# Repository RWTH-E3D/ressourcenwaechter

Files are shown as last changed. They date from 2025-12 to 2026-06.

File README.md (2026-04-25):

# Ressourcenwächter

*Resource Guardian - An open-source, modular Indoor Environmental Quality (IEQ) monitoring system featuring a gamified Graphical User Interface (GUI)*

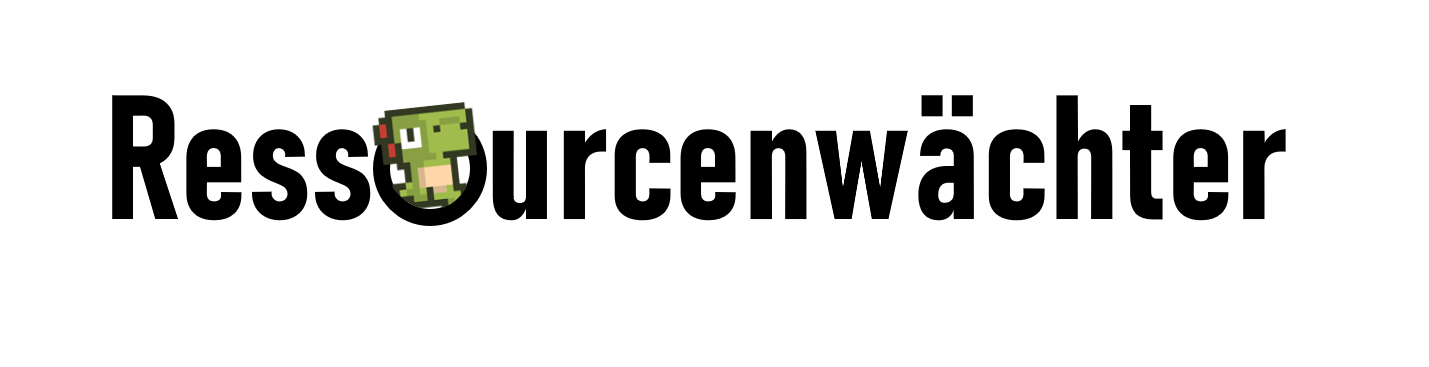
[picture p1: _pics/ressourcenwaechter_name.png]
Ressourcenwaechter name


**Resource Guardian's Wiki: [Link](https://rw.e3d.rwth-aachen.de/en/homepage-en/)**

## Overview

<!-- TOC -->
- [Ressourcenwächter](#ressourcenwächter)
  - [Overview](#overview)
  - [Key Features](#key-features)
  - [Design](#design)
  - [DIY Guide](#diy-guide)
  - [License](#license)
    - [Software \& Firmware](#software--firmware)
    - [Hardware](#hardware)
    - [Feedback System (Texts \& Concepts)](#feedback-system-texts--concepts)
    - [Documentation](#documentation)
    - [Artworks](#artworks)
  - [Acknowledgements](#acknowledgements)
  - [How to cite](#how-to-cite)
  - [Contributors](#contributors)
<!-- TOC -->

## Key Features

- **Modular IEQ monitoring system**

  Open-source system for monitoring key IEQ parameters, designed for real-world field studies and long-term deployment.

- **Multi-sensor data acquisition**

  Support for air temperature, humidity, illuminance, sound level, CO<sub>2</sub> concentration, VOC, wind speed, window status, electric power, and other IEQ sensors, with synchronized data collection and time-stamping.

- **Autonomous system**

  On-device GUI providing real-time visualization, intuitive interaction, and immediate feedback without requiring an external computer or internet connection. All data are stored locally on a microSD card.

- **Behavior-oriented feedback system**

  Context-aware feedback and recommendations aiming to support more resource-/energy-efficient and healthy user behavior, based on measured IEQ conditions.

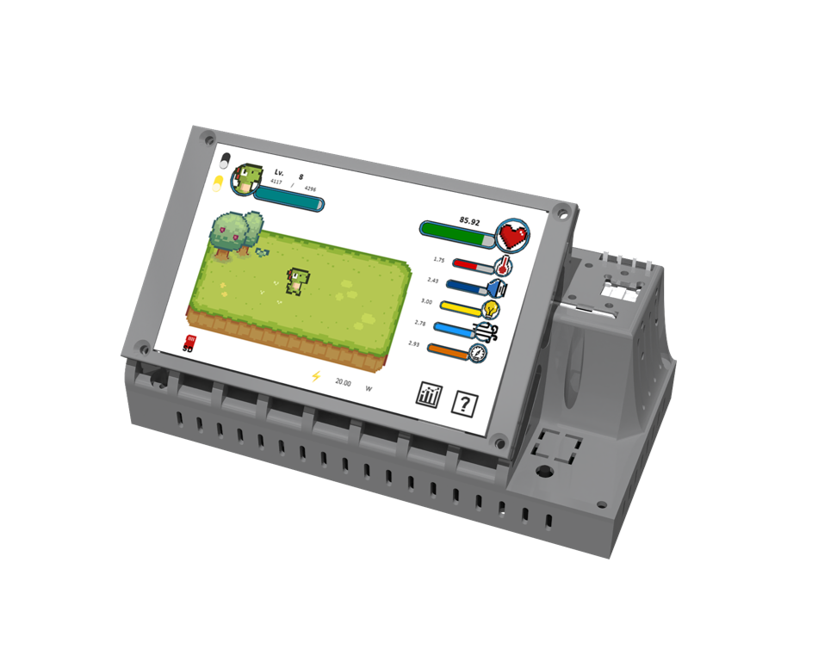
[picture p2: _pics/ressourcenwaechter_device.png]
Ressourcenwaechter monitoring device


<table>
<tr>
  <td align="center" valign="top">
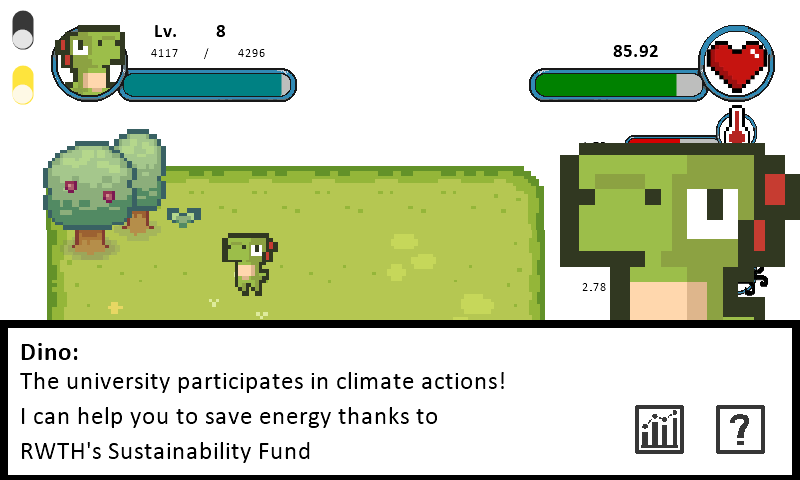
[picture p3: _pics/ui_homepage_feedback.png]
Feedback System
      
      <br/>
      <sub><strong>Feedback System</strong><br/>Resource Guardian can provide recommendations and energy-saving tips based on your current IEQ environment</sub>
  </td>
  <td align="center" valign="top">
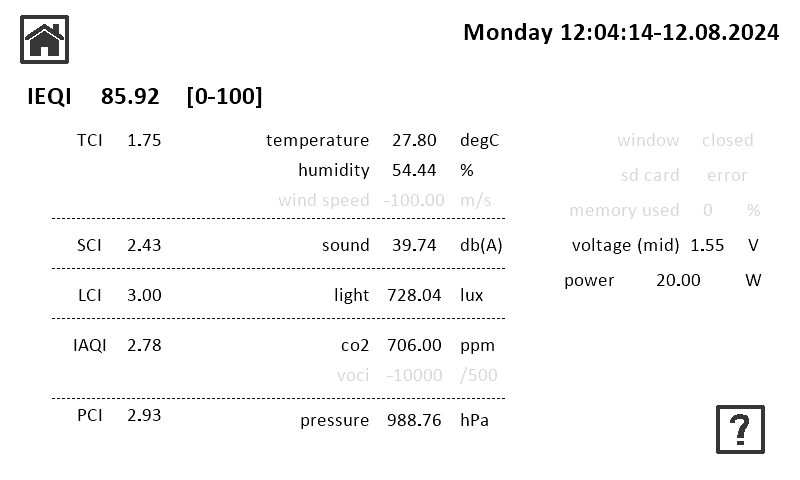
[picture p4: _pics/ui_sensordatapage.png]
Resizable GUI Small
      
      <br/>
      <sub><strong>Sensor Data</strong><br/>Resource Guardian's modular design allows real-time IEQ data to be displayed based on your sensor configuration.</sub>
  </td>
</tr>
</table>

## Design

1. [Hardware](./hardware)
   1. [Enclosure](./hardware/enclosure)
   2. [PCB](./hardware/pcb)
2. [Microcontroller Firmware](./firmware)
3. [GUI](./software/gui)

## DIY Guide

- Step 1: [Prepare enclosure](https://rw.e3d.rwth-aachen.de/en/wiki/prepare-enclosure/)
- Step 2: [Prepare PCB](https://rw.e3d.rwth-aachen.de/en/wiki/prepare-pcb/)
- Step 3: [Assembling Resource Guardian](https://rw.e3d.rwth-aachen.de/en/wiki/assembling-ressourcenwaechter/)

## License

The *Ressourcenwächter (Resource Guardian)* project is a mixed open-source project consisting of software, firmware, hardware designs, documentation, feedback content, and third-party artwork. Different components of the project are released under different licenses, as outlined below.

In general, this project may be used, modified, and redistributed, provided that appropriate attribution is given and the respective license terms of each component are respected. **Non-commercial** use is permitted for all components, while commercial use is restricted for parts of the project licensed under non-commercial Creative Commons licenses. Third-party assets remain subject to their original licenses.

Please read this section carefully before reusing or redistributing any part of the project.

### Software & Firmware

The codebase is structured into following main components:

1. **Firmware:** Code running on embedded microcontrollers.

2. **Software for touch display GUI:** Graphical user interface running directly on the monitoring device.

<!-- 3. **Desktop software:** Desktop applications running on computers. -->

Author: Qirui Huang

License: GNU General Public License v3.0 (GPL-3.0)

Unless stated otherwise, all software and firmware developed within this project are licensed under GPL-3.0. Any derivative work must be distributed under the same license.

### Hardware

Author: Qirui Huang

License: Creative Commons Attribution-NonCommercial-ShareAlike
4.0 International (CC BY-NC-SA 4.0)

This license applies to all hardware-related materials, including but not limited to schematics, PCB layouts, enclosure designs, and mechanical drawings.

Commercial use is not permitted. Adaptations must be shared under the same
license.

### Feedback System (Texts & Concepts)

Authors: Qirui Huang, Marc Syndicus, Anna Langenbeck, Anna Deriks, Sonja Herzogenrath

License: CC BY-NC-SA 4.0

This license applies to feedback texts, categorization schemes, behavioral
recommendation concepts, and related content, except for quotations and otherwise indicated parts.

### Documentation

Authors: Qirui Huang, Marc Syndicus

License: CC BY-NC-SA 4.0

This includes assembly guides, methodological documentation, and other written materials, except for quotations and otherwise indicated parts.

### Artworks

This project incorporates third-party assets. These assets are not covered by the software license and remain subject to their respective licenses:

- [Dino Characters](https://arks.itch.io/dino-characters) by @[ArksDigital](https://x.com/ArksDigital), license: free
- [Dino Family](https://demching.itch.io/dino-family) by @[DemChing](https://demching.itch.io/), license: CC-BY 4.0
- [Sprout Lands Asset Pack](https://cupnooble.itch.io/sprout-lands-asset-pack) by @[Cup Nooble](https://cupnooble.itch.io/), license: free for non-commercial projects
- [Hearts](https://fliflifly.itch.io/hearts-and-health-bar) by @[fliflifly](https://fliflifly.itch.io/), license: CC-0

All artworks not listed above are created by Qirui Huang and licensed under
CC BY-NC-SA 4.0.

[Back to top ↥](#overview)

## Acknowledgements

The project Ressourcenwächter was funded by RWTH Aachen University's Sustainability Fund (Ref. 02-2023-004). We are grateful for the support.

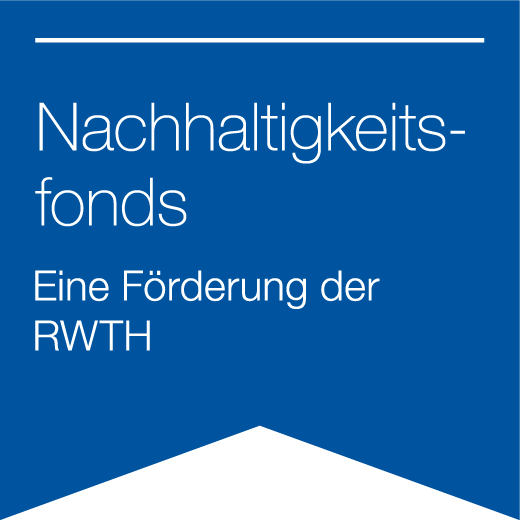
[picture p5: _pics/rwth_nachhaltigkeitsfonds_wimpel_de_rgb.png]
RWTH Nachhaltigkeitsfonds Wimpel


[Back to top ↥](#overview)

## How to cite

If you use Resource Guardian in your academic work, please cite our journal paper: https://doi.org/10.1016/j.buildenv.2026.114657

  **Examples:**

  BibTeX:

  ```bibtex
  @article{Huang_2026_Potential_Gamification_BAE,
    title = {The potential of gamification in IEQ monitoring: Open-source hardware development and field studies},
    journal = {Building and Environment},
    volume = {298},
    pages = {114657},
    year = {2026},
    issn = {0360-1323},
    doi = {https://doi.org/10.1016/j.buildenv.2026.114657},
    url = {https://www.sciencedirect.com/science/article/pii/S0360132326004622},
    author = {Qirui Huang and Marc Syndicus and Dono Jamoliddinova and Jérôme Frisch and Christoph {van Treeck}},
    keywords = {Indoor environmental quality, Gamification, Monitoring, User behavior, Hardware},
  }
  ```

  APA style:
  ```
  Huang, Q., Syndicus, M., Jamoliddinova, D., Frisch, J., & van Treeck, C. (2026). The potential of gamification in IEQ monitoring: Open-source hardware development and field studies. Building and Environment, 298, 114657. https://doi.org/10.1016/j.buildenv.2026.114657
  ```

## Contributors

<a href="https://github.com/RWTH-E3D/carbonfly/graphs/contributors">
  
</a>

[Back to top ↥](#overview)

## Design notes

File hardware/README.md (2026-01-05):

# Hardware Design

The hardware consists of two parts:

1. An enclosure optimized based on Computational Fluid Dynamics (CFD) simulations, including 3D printing files.
2. A Printed Circuit Board (PCB) for electrical connections to sensors and microcontrollers,

## Enclosure

The enclosure's design files can be found [here](./enclosure) (`./enclosure`), including:

1. Models in STL/STEP format
2. Project files for 3D printing

[DIY Guide: Prepare enclosure](https://rw.e3d.rwth-aachen.de/en/wiki/prepare-enclosure/)

## PCB

The PCB files can be found [here](./pcb) (`./pcb`), including:

1. Schematics
2. Production files

[DIY Guide: Prepare PCB](https://rw.e3d.rwth-aachen.de/en/wiki/prepare-pcb/)

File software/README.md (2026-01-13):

# Software

Currently, the software only includes GUI code for the touch display. Client programs for computers or mobile phones may be developed in future iterations.

[DIY Guide: Assembling Resource Guardian](https://rw.e3d.rwth-aachen.de/en/wiki/assembling-ressourcenwaechter/)

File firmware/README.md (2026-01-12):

# Microcontroller Firmware

The firmware for the microcontroller (Espressif ESP-32 DevKitC WROOM-32D/E) is written using [Arduino IDE](https://www.arduino.cc/en/software). 

[arduino_gui_TouchDisplay](./Arduino/arduino_gui_TouchDisplay) contains the latest firmware version for the Ressource Guardian. The libraries required are documented in `requirements.txt`.

[windsensor_rev_p_vs_c](./Arduino/windsensor_rev_p_vs_c) is the code implementation for evaluating calibration methods of different wind speed sensors as described in our paper.

[DIY Guide: Assembling Resource Guardian](https://rw.e3d.rwth-aachen.de/en/wiki/assembling-ressourcenwaechter/)

## How to configure the sensors being used?

See the [Wiki page](https://rw.e3d.rwth-aachen.de/en/wiki/sensor-configurations/) for supported sensors.

All supported I2C sensors can be automatically detected. If the address of your I2C sensor differs from the default address, you can modify it in `pin_cfg.h`.

Other supported analog sensors can be manually configured in `module_cfg.h`. Details are also available on our [Wiki page](https://rw.e3d.rwth-aachen.de/en/wiki/sensor-configurations/).

## How to calibrate the sensors?

See the [Wiki page](https://rw.e3d.rwth-aachen.de/en/wiki/sensor-calibration/) for sensor calibration.

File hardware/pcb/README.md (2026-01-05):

# Hardware Design

[DIY Guide: Prepare PCB](https://rw.e3d.rwth-aachen.de/en/wiki/prepare-pcb/)

## PCB

The relevant PCB documents can be found in this folder.

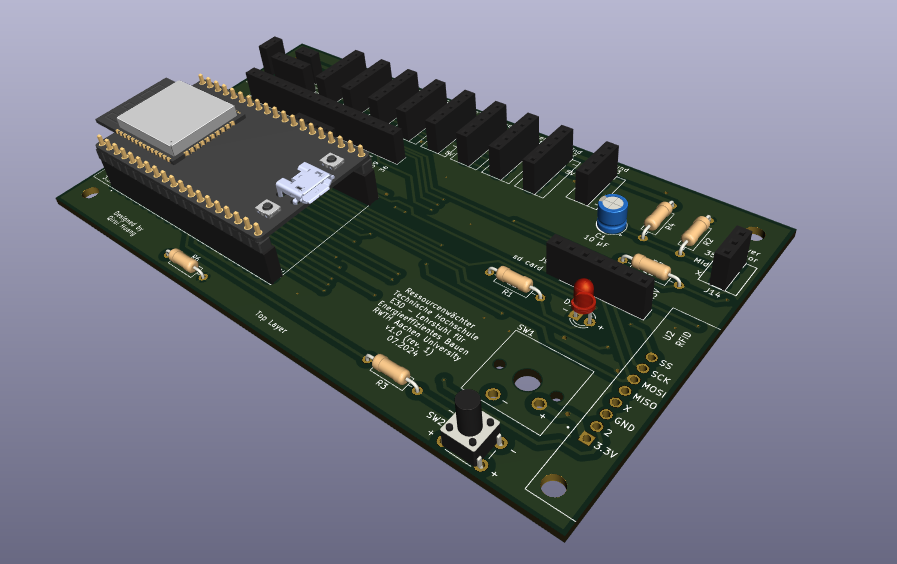
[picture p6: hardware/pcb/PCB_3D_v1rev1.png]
PCB 3D view
<br/>

We used [KiCAD](https://www.kicad.org/) for the design. To make DIY as easy as possible, we selected THT components instead of SMD.

Because there are no complex circuits and to reduce costs, we have chosen simple double-layer PCB, and the schematics for the top and bottom layers are shown below:

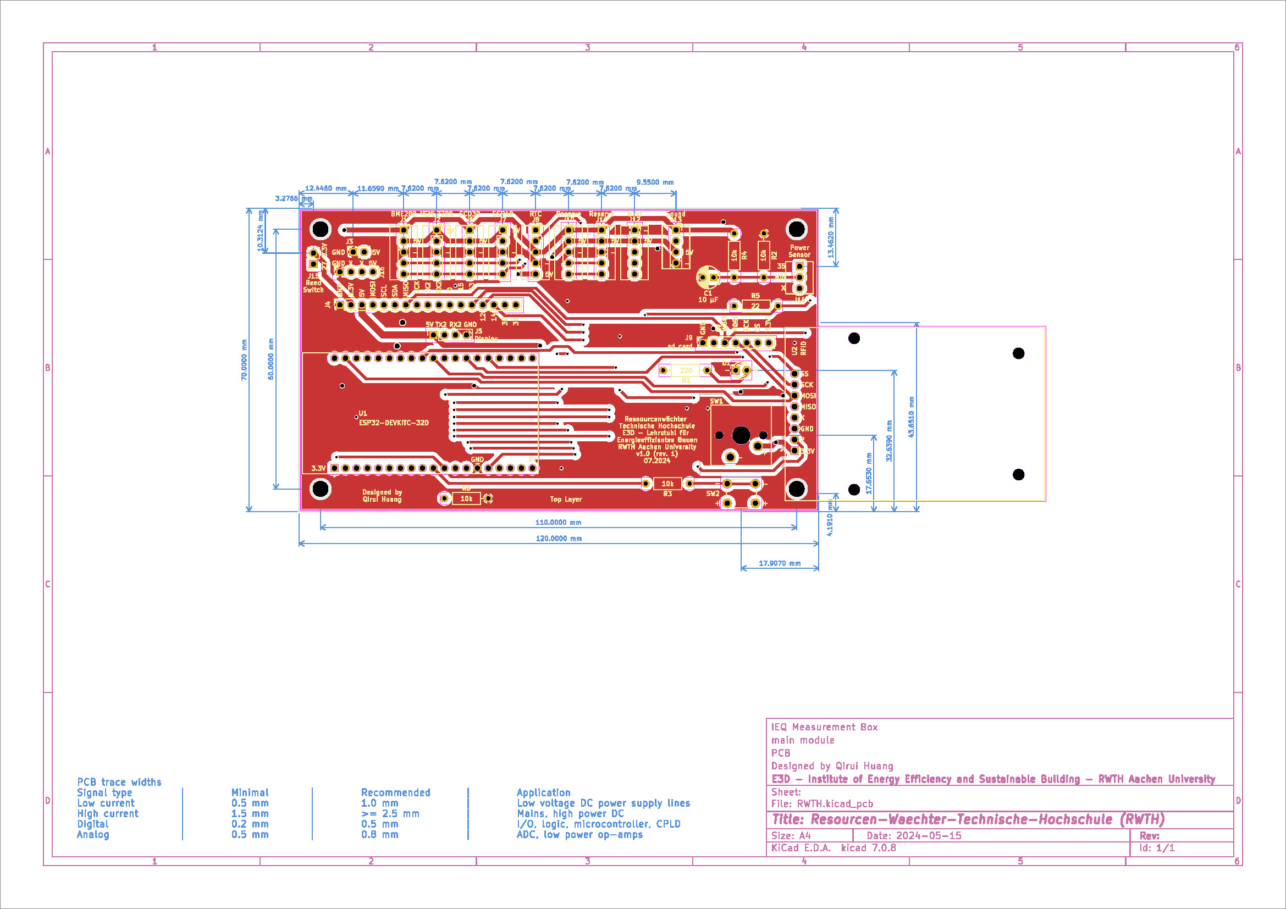
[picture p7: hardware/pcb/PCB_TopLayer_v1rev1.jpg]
PCB top layer view
<br/>

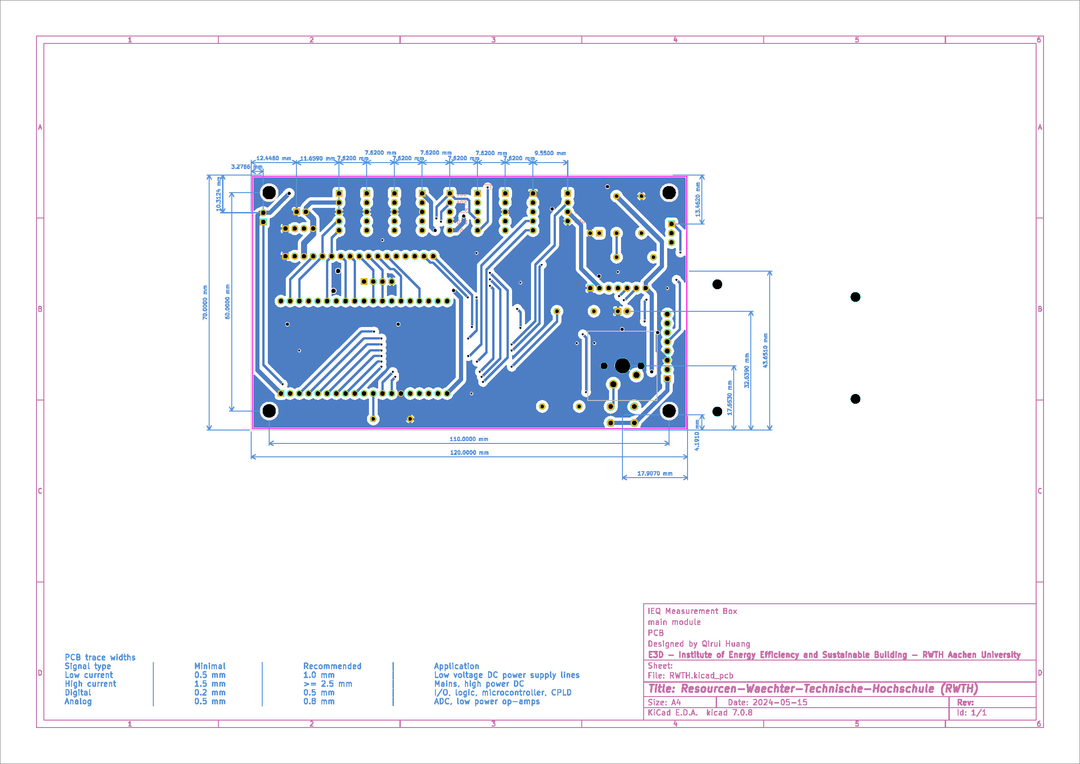
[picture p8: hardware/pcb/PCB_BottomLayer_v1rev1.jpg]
PCB bottom layer view
<br/>

### Production files

You can give the latest version of the `.zip` file in the [production file folder](./output) (`./output`) to the PCB manufacturer for production.

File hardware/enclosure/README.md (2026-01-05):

# Hardware Design

[DIY Guide: Prepare enclosure](https://rw.e3d.rwth-aachen.de/en/wiki/prepare-enclosure/)

## Enclosure

STL and STEP format files for the enclosure can be found in this folder, consisting of 3 parts:

1. `enclosure_base`

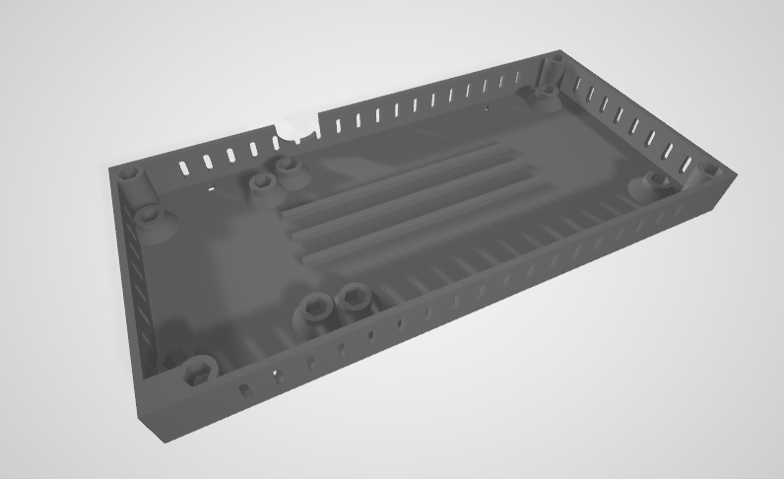
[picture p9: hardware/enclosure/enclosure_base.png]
enclosure base


2. `enclosure_display_case`

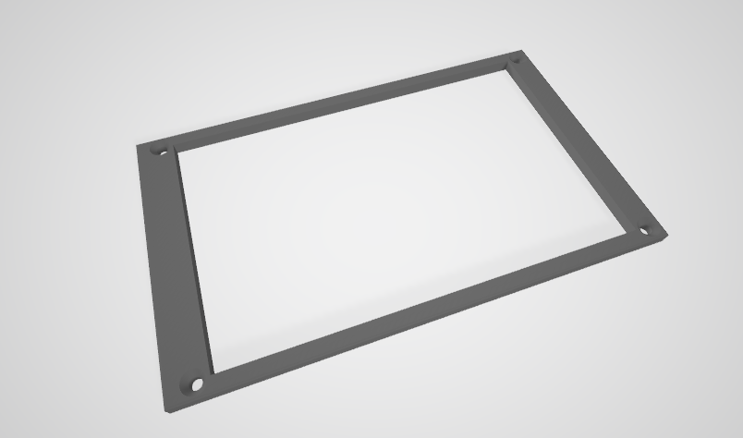
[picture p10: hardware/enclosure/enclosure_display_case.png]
enclosure display case


3. `enclosure_top`

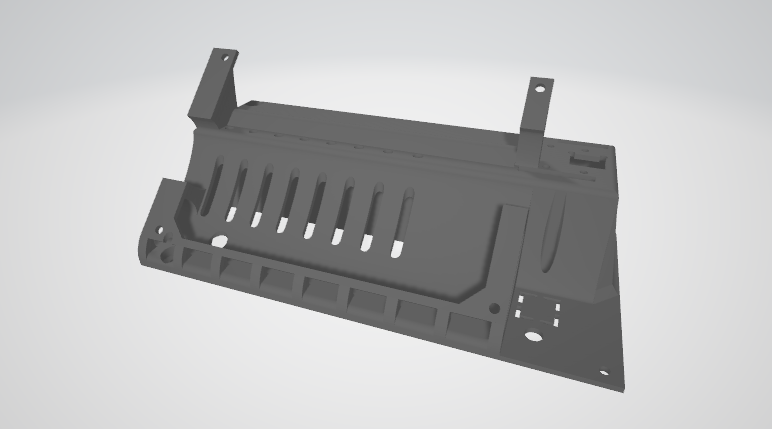
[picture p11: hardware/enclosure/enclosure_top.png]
enclosure top


### 3D printing files

Files for 3D printing can be found in the `3dprint` folder.

We used the [Orca Slicer](https://github.com/OrcaSlicer/OrcaSlicer) to slice the STL file. You can find the project files (`.3mf`) and the final `.gcode` file in the folder above for *Creality Ender 3 v2* and *Ender 5 plus*. If you're using the same 3D printer, you may use the `.gcode` file directly.

The following are the slicing parameters we used:

*Creality Ender 3 v2*:

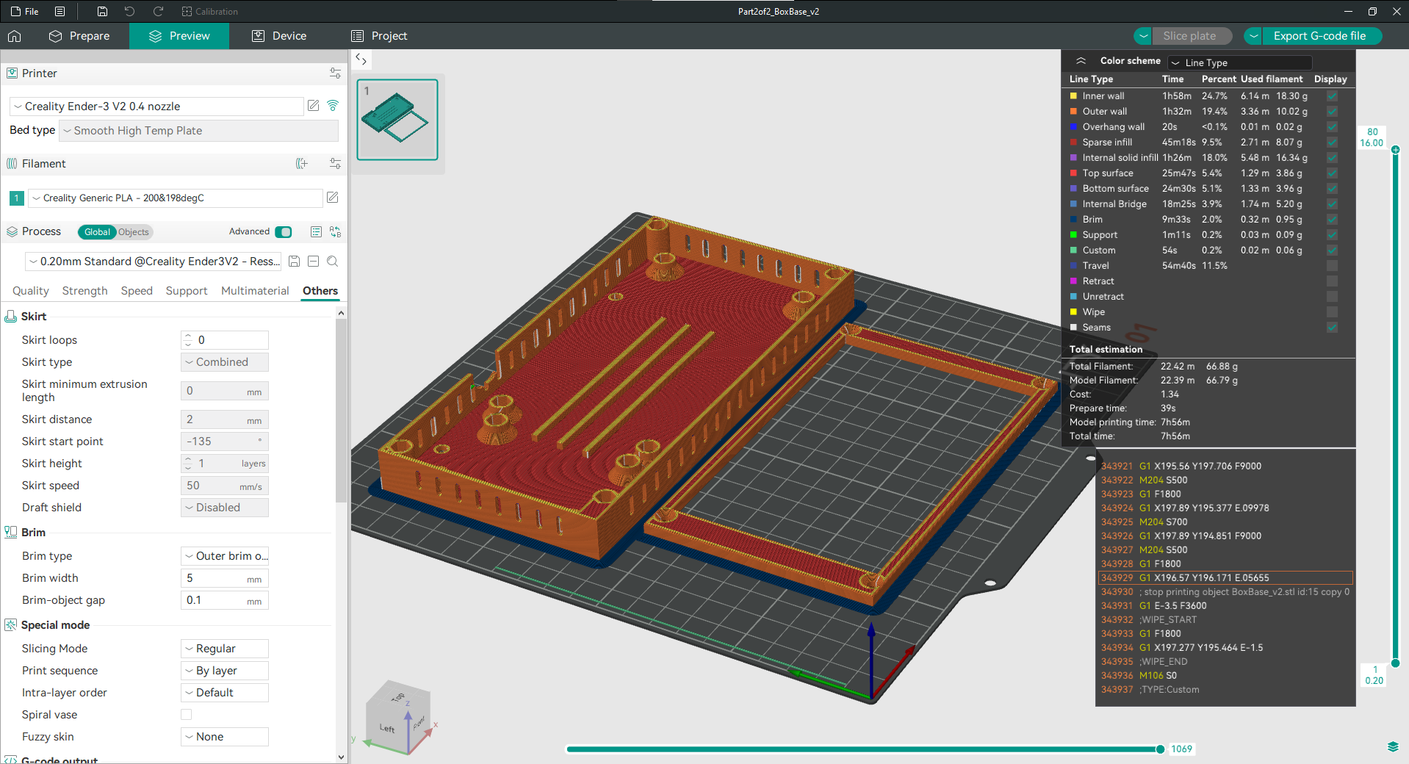
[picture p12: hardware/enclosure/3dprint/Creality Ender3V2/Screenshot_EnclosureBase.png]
Ender3 V2 Screenshot Enclosure Base


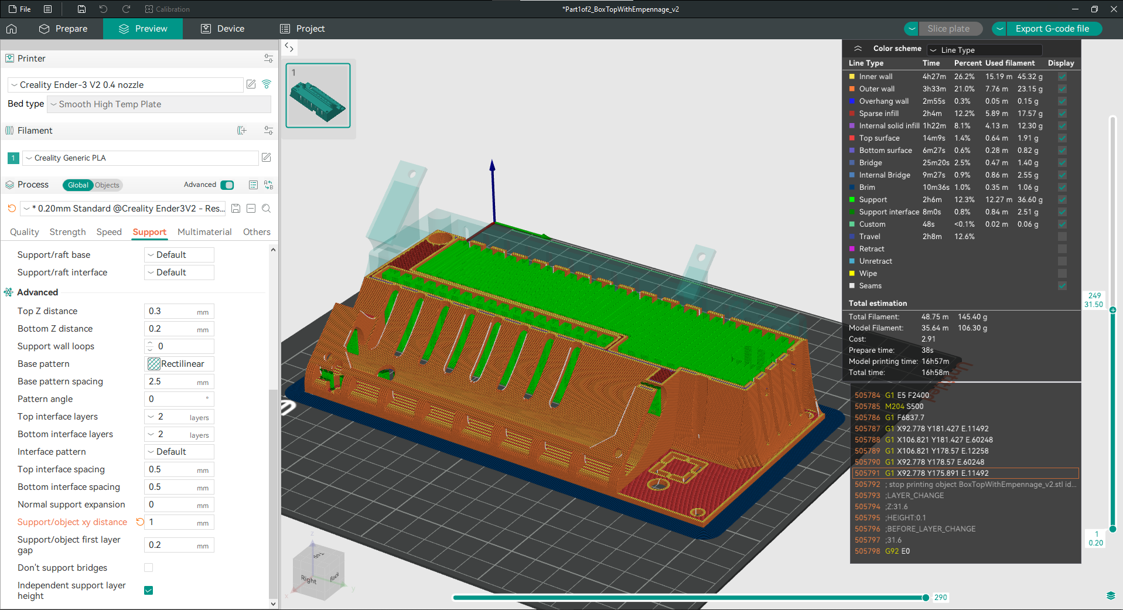
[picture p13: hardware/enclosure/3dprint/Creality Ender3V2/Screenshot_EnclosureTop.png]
Ender3 V2 Screenshot Enclosure Top


*Creality Ender 5 plus*:

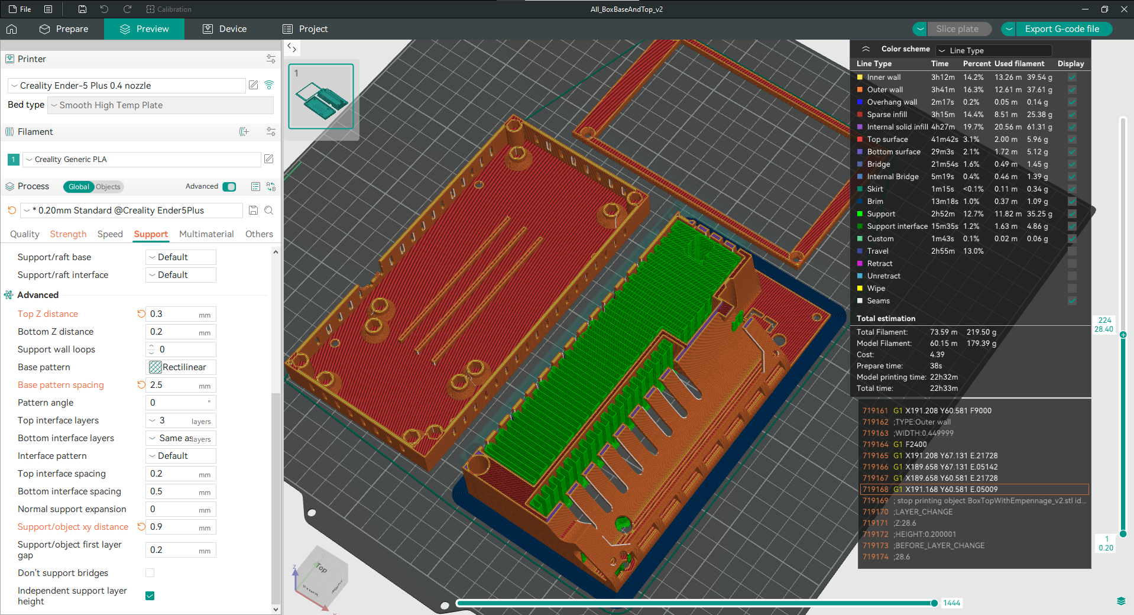
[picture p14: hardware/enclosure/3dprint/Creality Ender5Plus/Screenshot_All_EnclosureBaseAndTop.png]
Ender5 plus Screenshot Enclosure Base and Top


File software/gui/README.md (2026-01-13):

# GUI

GUI files are provided for the following two touch displays:

1. Nextion Intelligent HMI Display 5" [NX8048P050-011R](https://nextion.tech/datasheets/nx8048p050-011r/) (Resistive) or [NX8048P050-011C](https://nextion.tech/datasheets/nx8048p050-011c/) (Capacitive)
2. Taojingchi [TJC8048X550_011R](http://wiki.tjc1688.com/product/new_datasheet/X5/TJC8048X550_011R.html) (Resistive) or [TJC8048X550_011C](http://wiki.tjc1688.com/product/new_datasheet/X5/TJC8048X550_011C.html) (Capacitive)

Both resistive and capacitive versions are supported, with no differences beyond the hardware itself. TJC is only available in certain regions but typically costs less.

The GUI for Nextion touch display is developed using [Nextion Editor](https://nextion.tech/editor_guide/). The GUI for TJC touch display is developed using the [USART HMI](http://wiki.tjc1688.com/download/usart_hmi.html) provided by TJC. The user interfaces are largely identical, though USART HMI only supports Chinese language.

If you wish to install both Nextion Editor and USART HMI for development, please refer to the instructions in [`TJC_USART_HMI/README.txt`](./TJC_USART_HMI/README.txt).

> For code syntax in Nextion Editor, refer to: [The Nextion Instruction Set](https://nextion.tech/instruction-set/)

> For code syntax in USART HMI, refer to [USART HMI Grammar](http://wiki.tjc1688.com/grammar/index.html) (should be the same as in Nextion Editor)

## How to change GUI?

The following steps use Nextion Editor as an example. The process is identical for USART HMI:

1. Open the corresponding language version of the `.hmi` project file in Nextion Editor, e.g., `Nextion_HMI/GUI_EN/gui_nextion_en.hmi` for english version
2. To replace Dino's animations (e.g., using custom characters or skins), replace the images with ID **1 - 40** and **85 - 104** in the left image library (area **A** in the figure below). These represent each frame of Dino's character animation (85 x 85 pixels):

   1. **1 - 28**: Animation frames for standing
   2. **29 - 40**: Animation frames for left/right movement after click 
   3. **85 - 104**: Animation frames for Dino at Level 0

Corresponding code can be found in `tmDino(Timer)` (areas **B** and **C**).

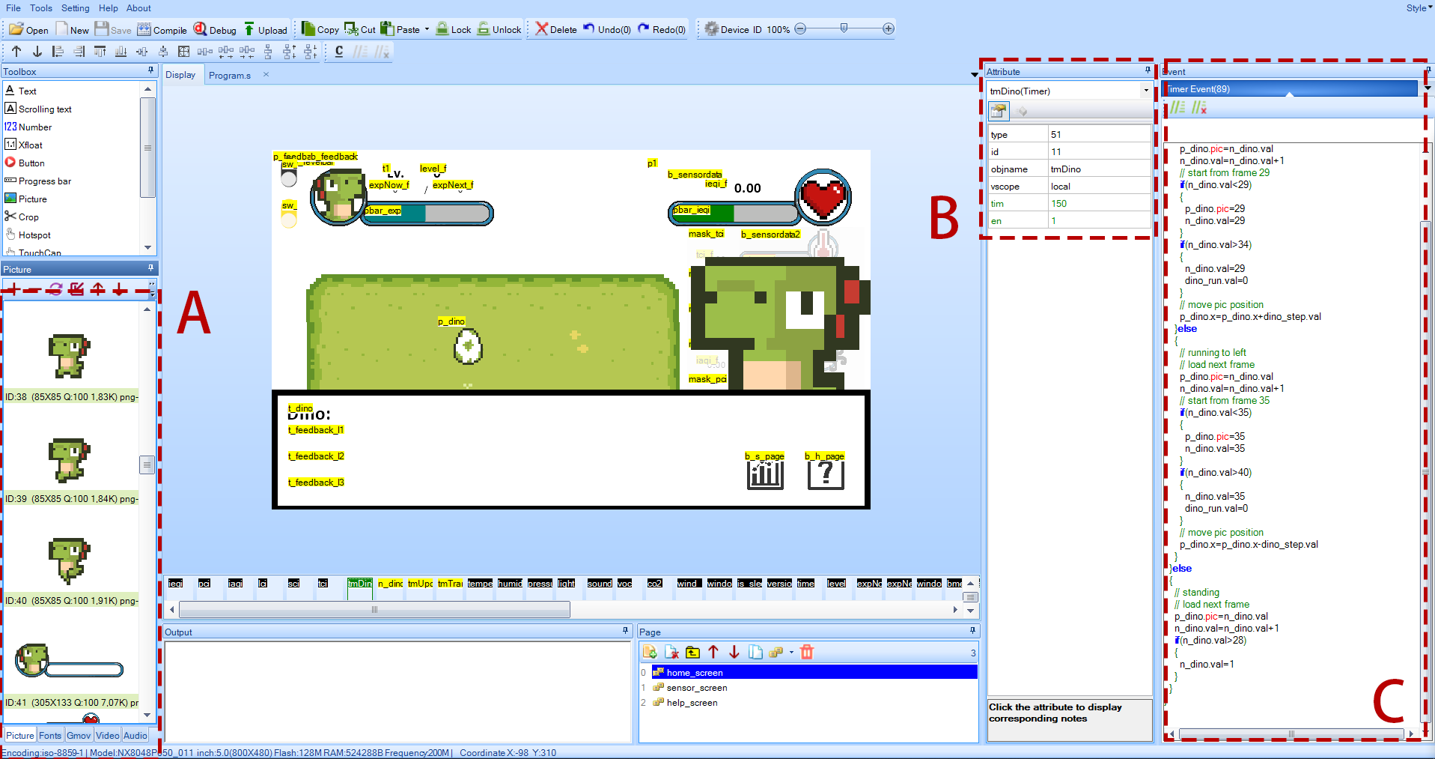
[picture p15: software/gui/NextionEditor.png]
Nextion Editor Screenshot


To replace the island background, modify images with ID **59 - 84**, which correspond to backgrounds for levels 0 - 25 (800 x 480 pixels). The relevant code can be found in `tmIsland(Timer)`.

To add more level-specific backgrounds, add new images to the picture library (maintaining 800 x 480 pixels) and modify the logic in `tmIsland(Timer)`.

Example:

```
...
}else if(level.val==24)
{
  p_island.pic=83
}else if(level.val==NEW_LEVEL)
{
  p_island.pic=NEW_BACKGROUND_PIC_ID
}else
{
  p_island.pic=84
}
```

## How to modify/translate the feedback content?

To modify or translate the feedback content, you may find all feedback messages and the relevant code in `b_feedback(Button) - Touch Release Event`. Each feedback message consists of three lines of text, with no more than 50 characters per line.

Example:

```
t_feedback_l1.txt="The university participates in climate actions!"
t_feedback_l2.txt="I can help you to save energy thanks to "
t_feedback_l3.txt="RWTH's Sustainability Fund"
```

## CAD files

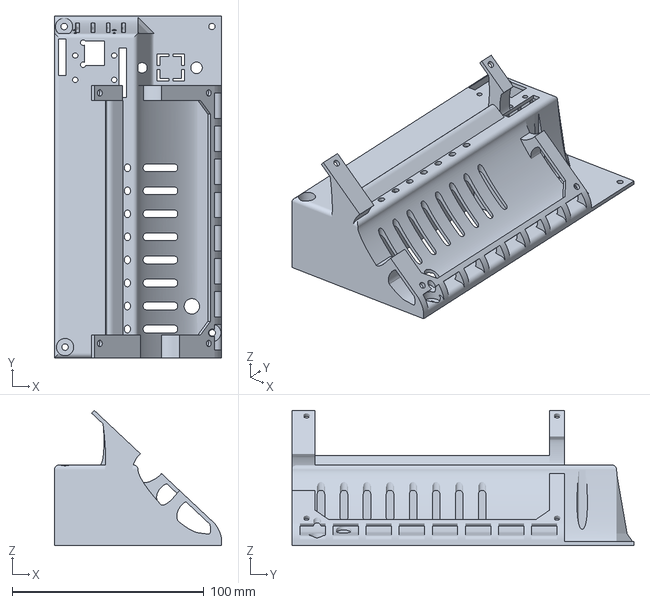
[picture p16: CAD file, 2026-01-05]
hardware/enclosure/3dprint/Creality Ender3V2/Part1of2_EnclosureTop.3mf
87.0 x 178.0 x 70.4 mm

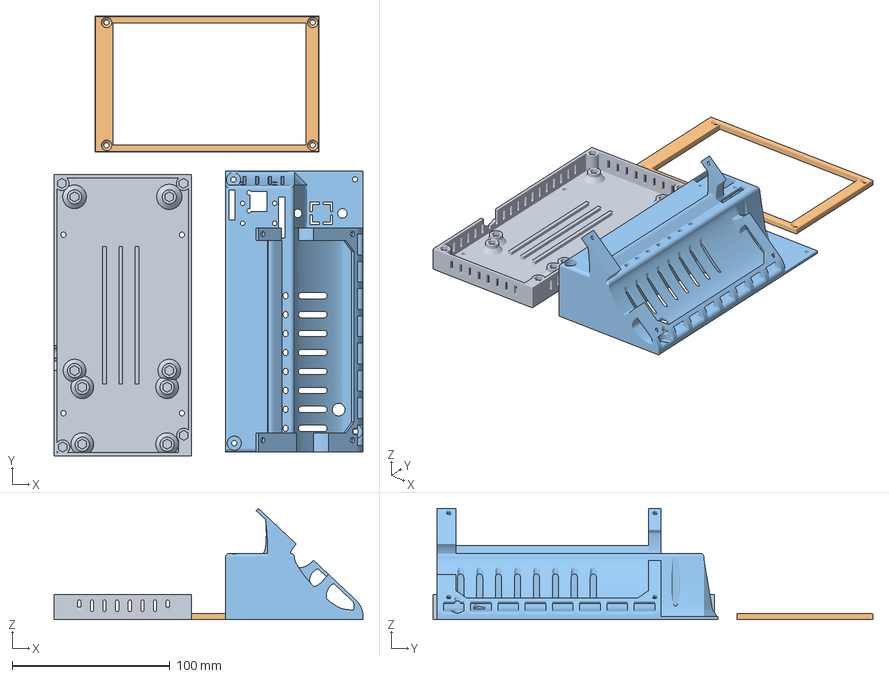
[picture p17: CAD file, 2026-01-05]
hardware/enclosure/3dprint/Creality Ender5Plus/All_EnclosureBaseAndTop.3mf
195.6 x 278.4 x 70.4 mm
BoxBase_v2.stl
DisplayCase_v2.stl
BoxTopWithEmpennage_v2.stl

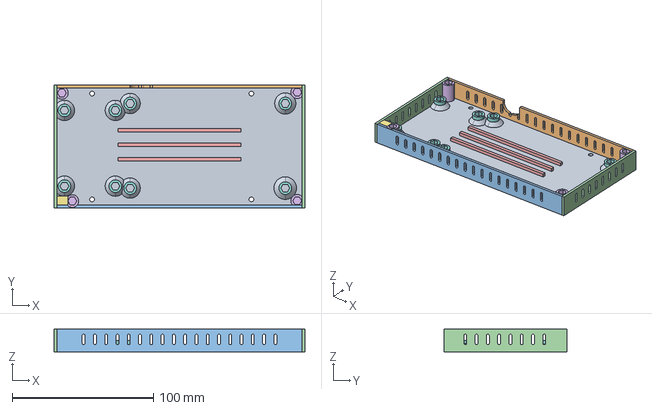
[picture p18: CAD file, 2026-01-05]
hardware/enclosure/enclosure_base.stp
178.0 x 87.0 x 16.0 mm

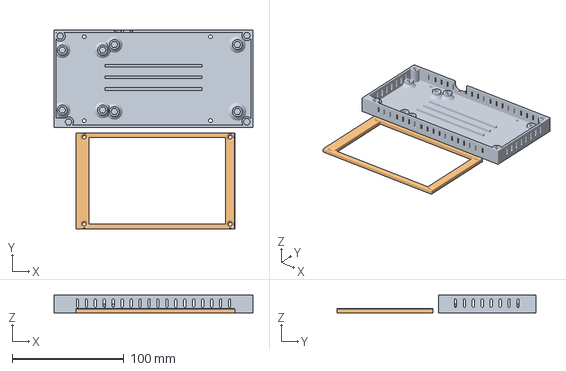
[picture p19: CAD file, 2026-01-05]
hardware/enclosure/3dprint/Creality Ender3V2/Part2of2_EnclosureBase.3mf
178.0 x 177.9 x 16.0 mm
BoxBase_v2.stl
DisplayCase_v2.stl

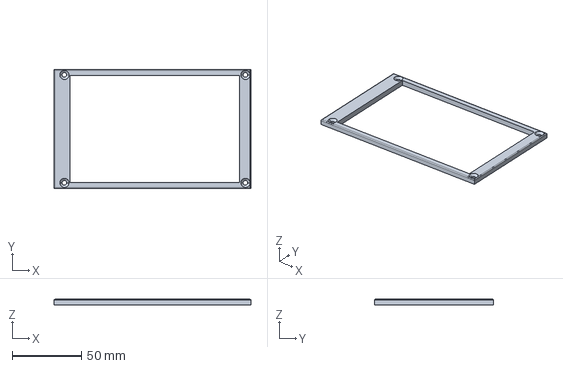
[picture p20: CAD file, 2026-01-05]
hardware/enclosure/enclosure_display_case.stp
142.0 x 86.0 x 4.00 mm

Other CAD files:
hardware/enclosure/enclosure_top.stp
hardware/enclosure/enclosure_display_case.stl

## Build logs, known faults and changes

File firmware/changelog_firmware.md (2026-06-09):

## Change Log

### v1.3.0

09.06.2026

- Update: ESP32 firmware
    - Support Sensirion SCD4x CO2 sensors

### v1.2.2

03.04.2025

- Fix input mode of button's GPIO

### v1.2.1

04.02.2025

- Update: ESP32 firmware
    - Provide an option to control whether ASC for SCD30 should be enabled or not.

### v1.2.0

22.01.2025

- Update: ESP32 firmware
    - add calibration methods for wind speed sensors
    - add comments

### v1.1.0

27.11.2024

- Update: ESP32 firmware - calibration & fix some bugs

### v1.0.1

23.10.2024

- Hotfix: ESP32 firmware - add software debouncing to prevent the "touch" issue if using an usb charger with noisy power supply or false button presses

### v1.0.0

09.09.2024

Release version v1.0.0 for field study, contains UI for touch display and firmware for esp32. Removed (temporarily) desktop software as it is not planned to be used in the field study.

- New: support DS18B20 for radiant temperature
- Update: UI (display)
- Update: fine tuned default settings of all comfort models in the firmware
- Add: resources of artworks for UI
- Add: results of CFD for hardware design
- Fix: corrected PCB design (footprints)

### v0.2.1
21.06.2024
- New: support power sensor SCT013 (current version 100A / 0-50mA)
- Update: UI (display)
- Update: fix bug for analog sensors via ADC (10->12bit)

### v0.2.0
11.06.2024
- New: new UI (display)
- New: Feedbacksystem in Nextion Display
- Update: change MC from Arduino Nano to ESP32
- Update: optimized code for MC

### v0.1.6
28.06.2021
- Updated: support high dpi
    - tested on 2K monitor (text 100% - 200%)

### v0.1.5
27.06.2021
- Fixed some code errors
- Added:
    - Release version for windows user 
        - by using winpython environment and batch command
        - user can open the application by double-clicking batch file "\_\_RUN\_\_.bat"
        - no need to install python environment or other python packages

### v0.1.4
15.06.2021
- Updated: re-design GUI
- Added:
    - calculator for CLO value
    - setup assistant
    - quick start guide
- Optimized: also works on macOS (10.11 or higher)

### v0.1.3
05.06.2021
- Added: multi-language support (english/german/chinese)

### v0.1.2
03.06.2021
- Added: analysis window
- Updated: GUI
    - changed all fonts into Arial

### v0.1.1
25.05.2021
- Updated: optimized algorithm in Arduino
    - support static PMV model (ISO 7730) for thermal comfort index
        - default clo (clothing insulation) value = 0.7
        - default metabolic rate = 1.2 met (office work)
- Updated: Arduino GUI

### v0.1.0
24.05.2021
- Updated: optimized algorithm of all comfort index
    - support adaptive model (EN 16798-1 2019) and static PMV model (ISO 7730) for thermal comfort index
        - adaptive model:
            - support calculation of outdoor running mean temperature by using free API of openweathermap
        - PMV:
            - add clo (clothing insulation) value in setting window
            - default metabolic rate = 1.2 met (office work)
- Added: platform check to avoid win10toast lib doesn't work on macOS or other platform
- Added: current outdoor temperature and the "feels like" temperature in main window

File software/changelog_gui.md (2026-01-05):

## Change Log

### v1.2.0

19.12.2024

- Update: UI (display) - add Pomodoro Technique (tomato technique), a time management method to give the feedbacks every 30 min. automatically.

### v1.1.0

27.11.2024

- Add: USART-HMI and TFT files for TJC touch displays (TJC8048X550_011R/TJC8048X550_011C)
- Update: UI (display) - add language DE

### v1.0.2

24.10.2024

- Update: UI (display)
  - add birth stage for dino (egg incl. move and hatch at level 0)
  - add different color for IEQI color bar based on current IEQI values (0-33 red, 33-67 yellow, 67-90 light green, 90-100 green)
  - update credits info on the help page

### v1.0.1

15.10.2024

- Update: UI (display) - feedbacksystem

### v1.0.0

09.09.2024

Release version v1.0.0 for field study, contains UI for touch display and firmware for esp32. Removed (temporarily) desktop software as it is not planned to be used in the field study.

- New: support DS18B20 for radiant temperature
- Update: UI (display)
- Update: fine tuned default settings of all comfort models in the firmware
- Add: resources of artworks for UI
- Add: results of CFD for hardware design
- Fix: corrected PCB design (footprints)

### v0.2.1
21.06.2024
- New: support power sensor SCT013 (current version 100A / 0-50mA)
- Update: UI (display)
- Update: fix bug for analog sensors via ADC (10->12bit)

### v0.2.0
11.06.2024
- New: new UI (display)
- New: Feedbacksystem in Nextion Display
- Update: change MC from Arduino Nano to ESP32
- Update: optimized code for MC

### v0.1.6
28.06.2021
- Updated: support high dpi
    - tested on 2K monitor (text 100% - 200%)

### v0.1.5
27.06.2021
- Fixed some code errors
- Added:
    - Release version for windows user 
        - by using winpython environment and batch command
        - user can open the application by double-clicking batch file "\_\_RUN\_\_.bat"
        - no need to install python environment or other python packages

### v0.1.4
15.06.2021
- Updated: re-design GUI
- Added:
    - calculator for CLO value
    - setup assistant
    - quick start guide
- Optimized: also works on macOS (10.11 or higher)

### v0.1.3
05.06.2021
- Added: multi-language support (english/german/chinese)

### v0.1.2
03.06.2021
- Added: analysis window
- Updated: GUI
    - changed all fonts into Arial

### v0.1.1
25.05.2021
- Updated: optimized algorithm in Arduino
    - support static PMV model (ISO 7730) for thermal comfort index
        - default clo (clothing insulation) value = 0.7
        - default metabolic rate = 1.2 met (office work)
- Updated: Arduino GUI

### v0.1.0
24.05.2021
- Updated: optimized algorithm of all comfort index
    - support adaptive model (EN 16798-1 2019) and static PMV model (ISO 7730) for thermal comfort index
        - adaptive model:
            - support calculation of outdoor running mean temperature by using free API of openweathermap
        - PMV:
            - add clo (clothing insulation) value in setting window
            - default metabolic rate = 1.2 met (office work)
- Added: platform check to avoid win10toast lib doesn't work on macOS or other platform
- Added: current outdoor temperature and the "feels like" temperature in main window

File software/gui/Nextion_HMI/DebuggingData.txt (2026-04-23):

version.txt="0.2.1"
time.txt="Monday 12:04:14-12.08.2024"
is_sleep.val=0
sd_ava.val=0
sd_used.val=0
level.val=8
expNow.val=4117
expNext.val=4296
window_ava.val=0
window_is_open.val=0
power_ava.val=1
poweradc.val=155
power.val=2000
bme280_ava.val=1
temperature.val=2780
humidity.val=5444
pressure.val=98876
radtemp_ava.val=1
radtemp.val=2730
sgp40_ava.val=0
voc.val=-100
veml7700_ava.val=1
light.val=72804
sound_ava.val=1
sound.val=3974
windspeed_ava.val=0
wind_speed.val=-10000
scd30_ava.val=1
co2.val=70600
tci.val=175
sci.val=243
lci.val=300
pci.val=293
iaqi.val=278
ieqi.val=8592

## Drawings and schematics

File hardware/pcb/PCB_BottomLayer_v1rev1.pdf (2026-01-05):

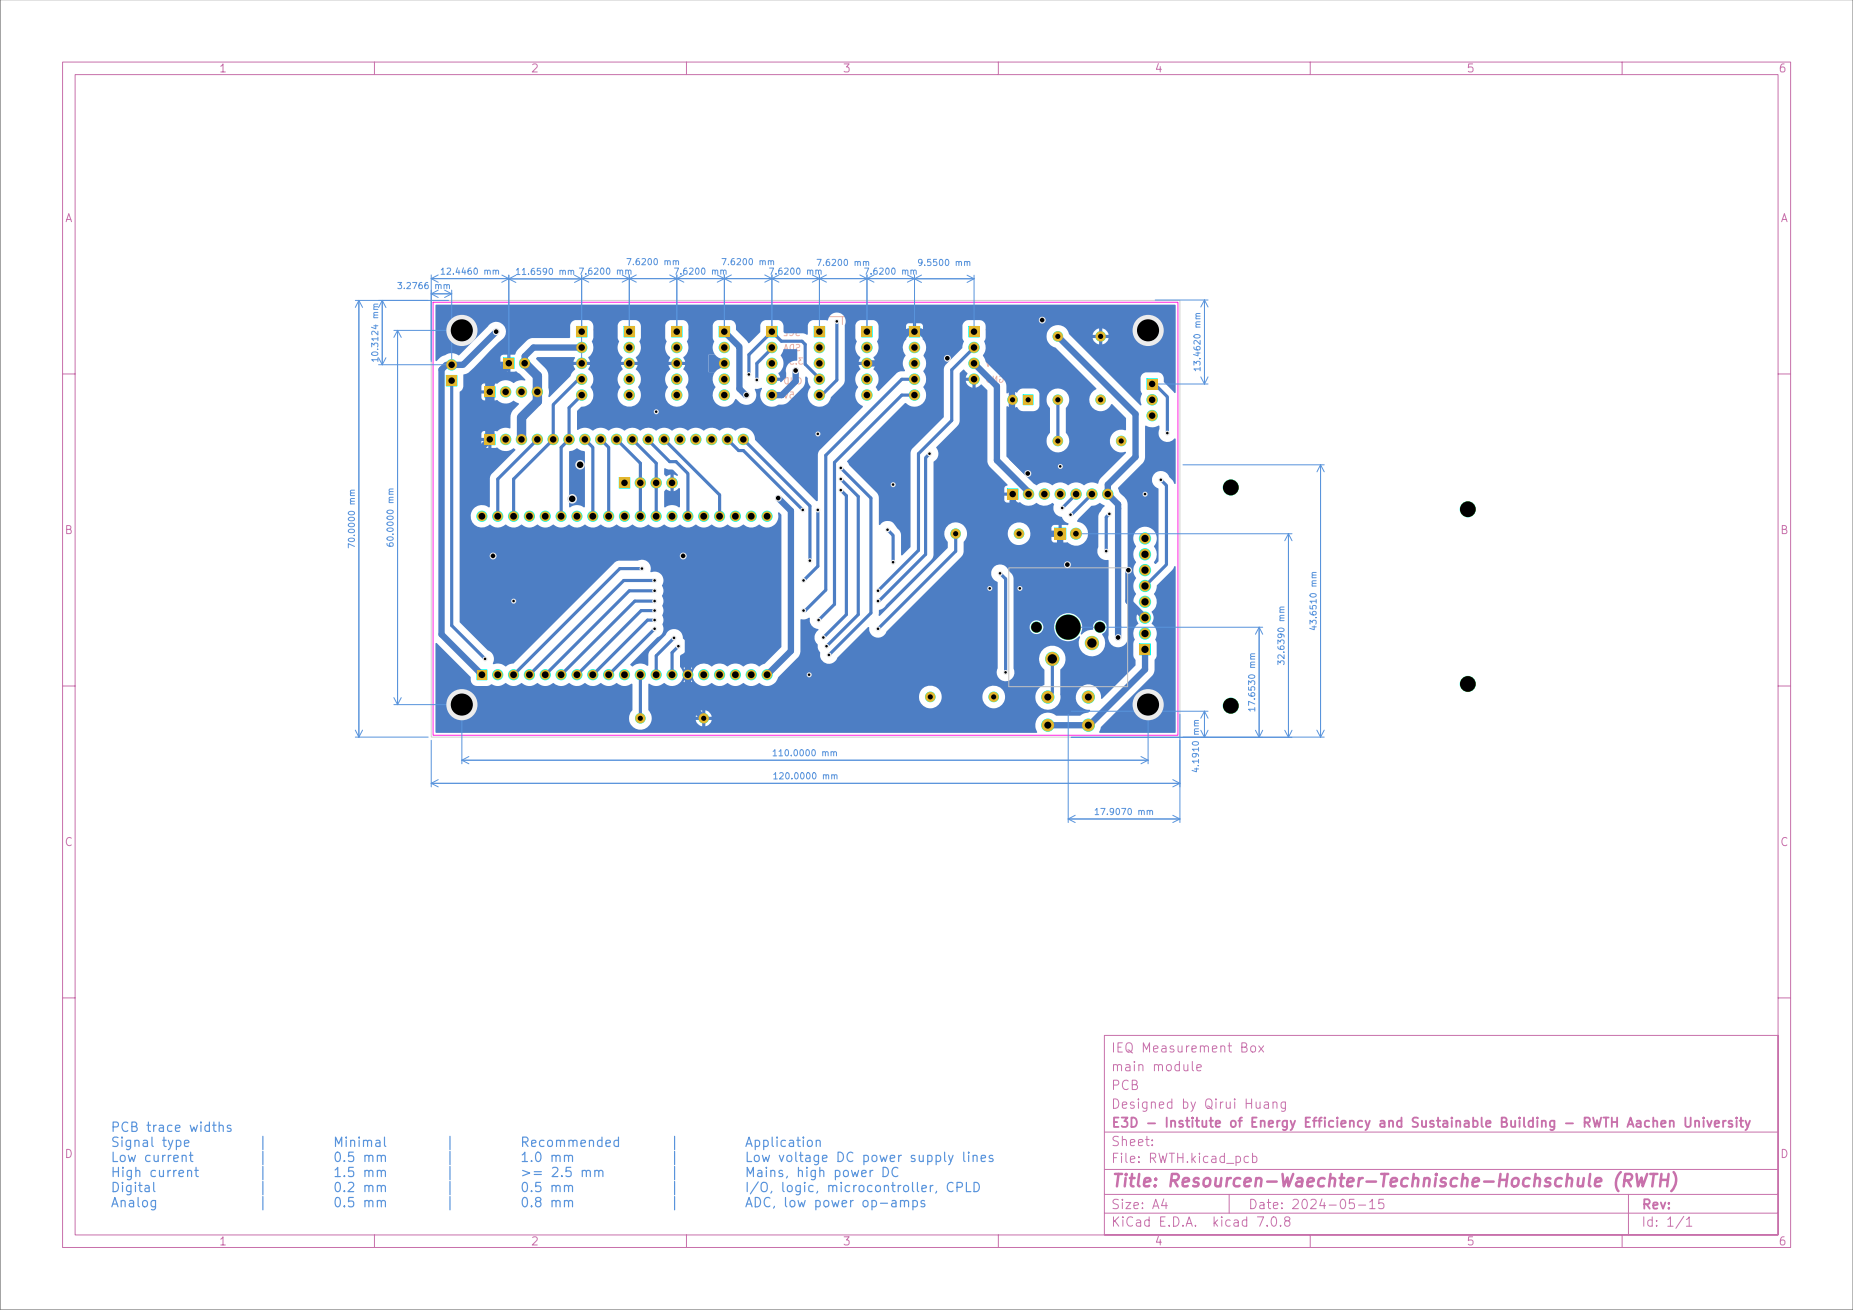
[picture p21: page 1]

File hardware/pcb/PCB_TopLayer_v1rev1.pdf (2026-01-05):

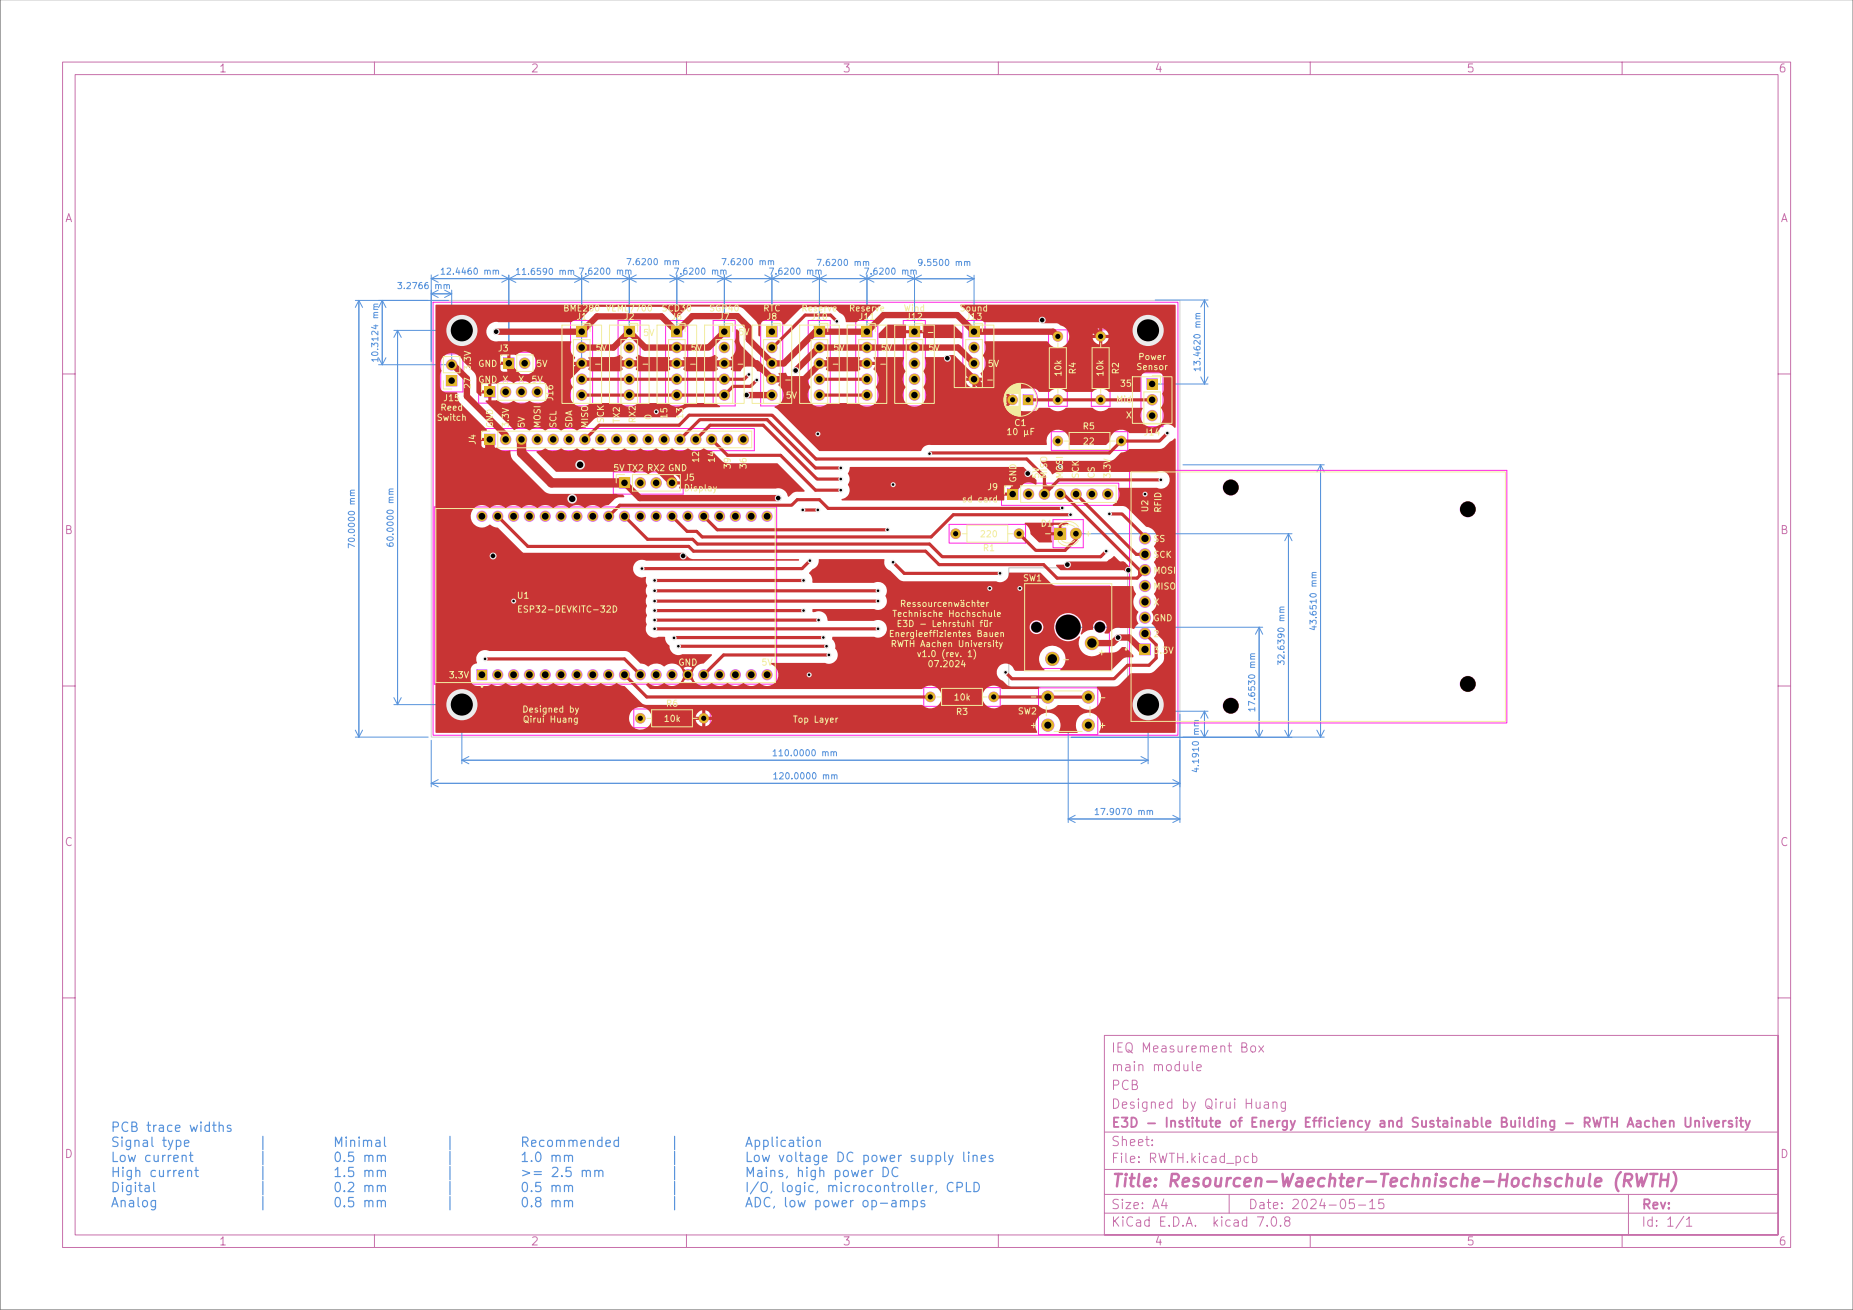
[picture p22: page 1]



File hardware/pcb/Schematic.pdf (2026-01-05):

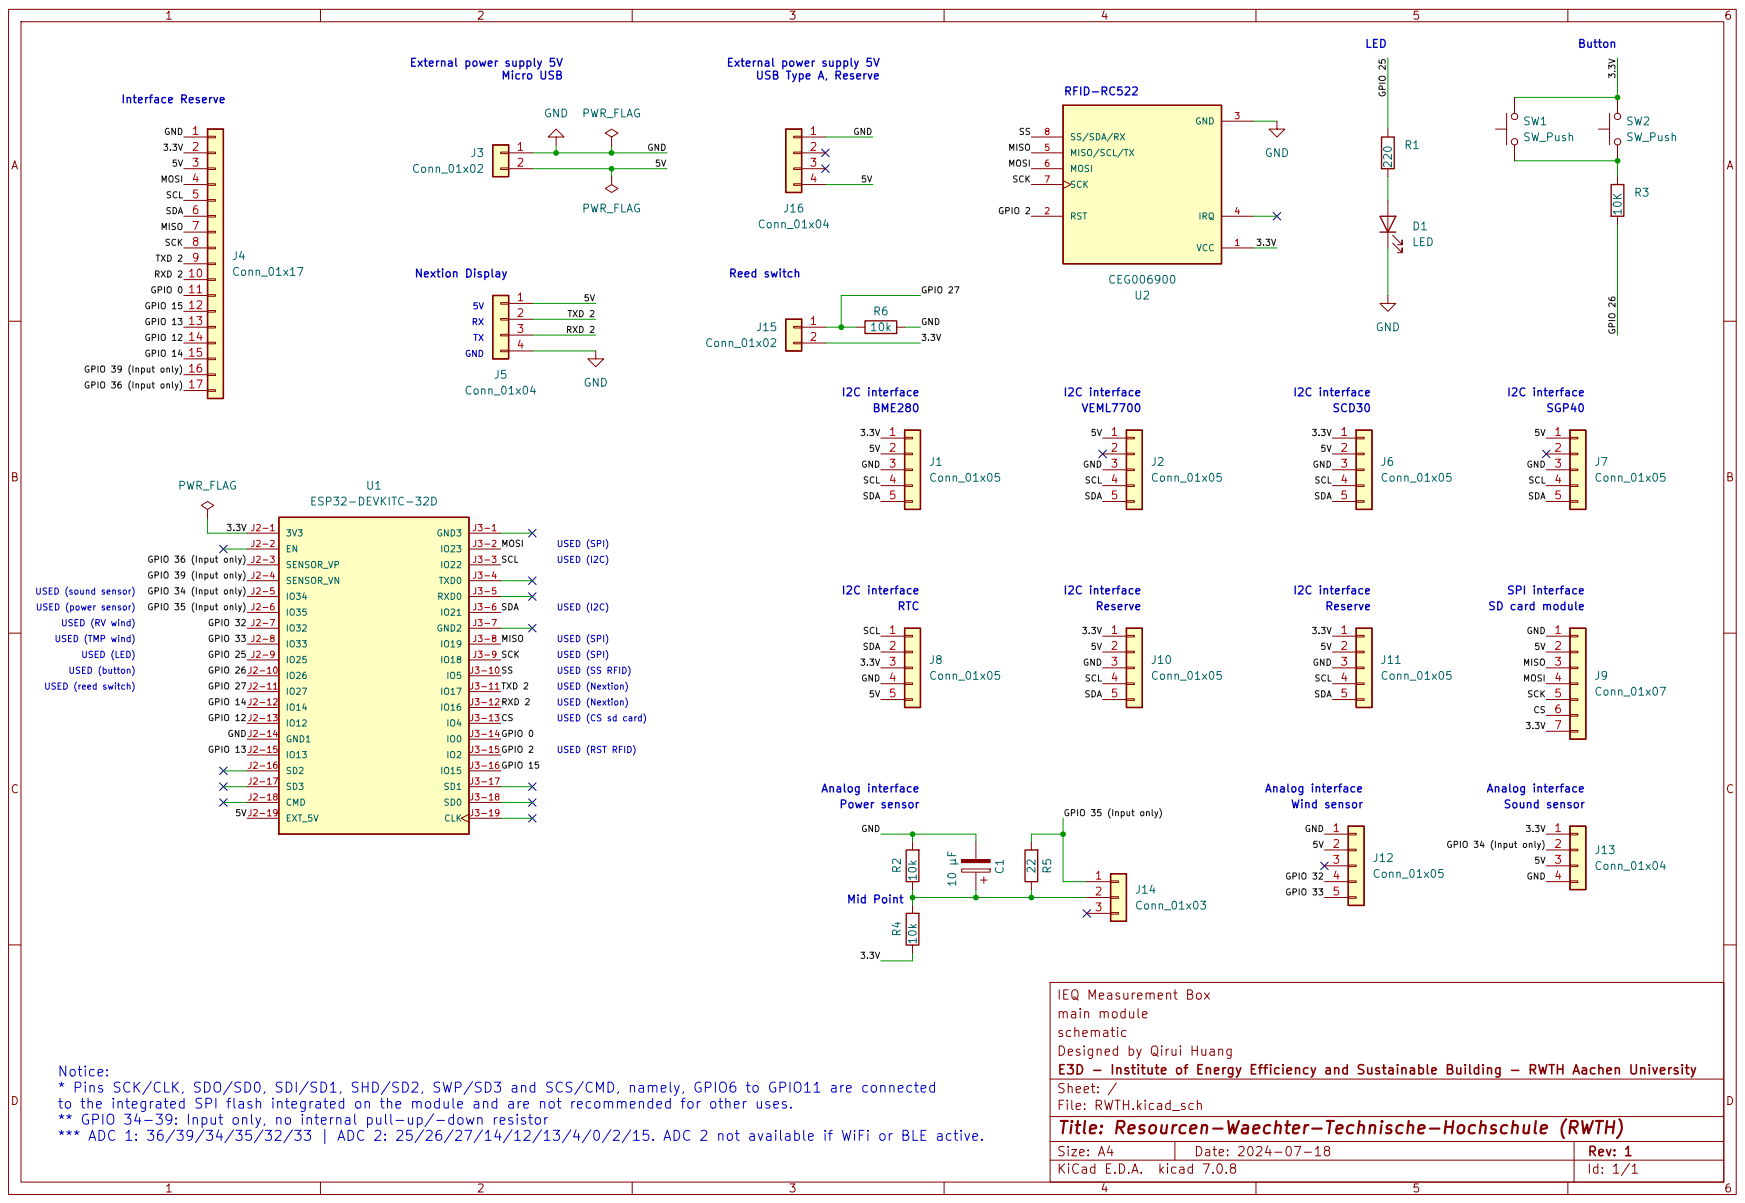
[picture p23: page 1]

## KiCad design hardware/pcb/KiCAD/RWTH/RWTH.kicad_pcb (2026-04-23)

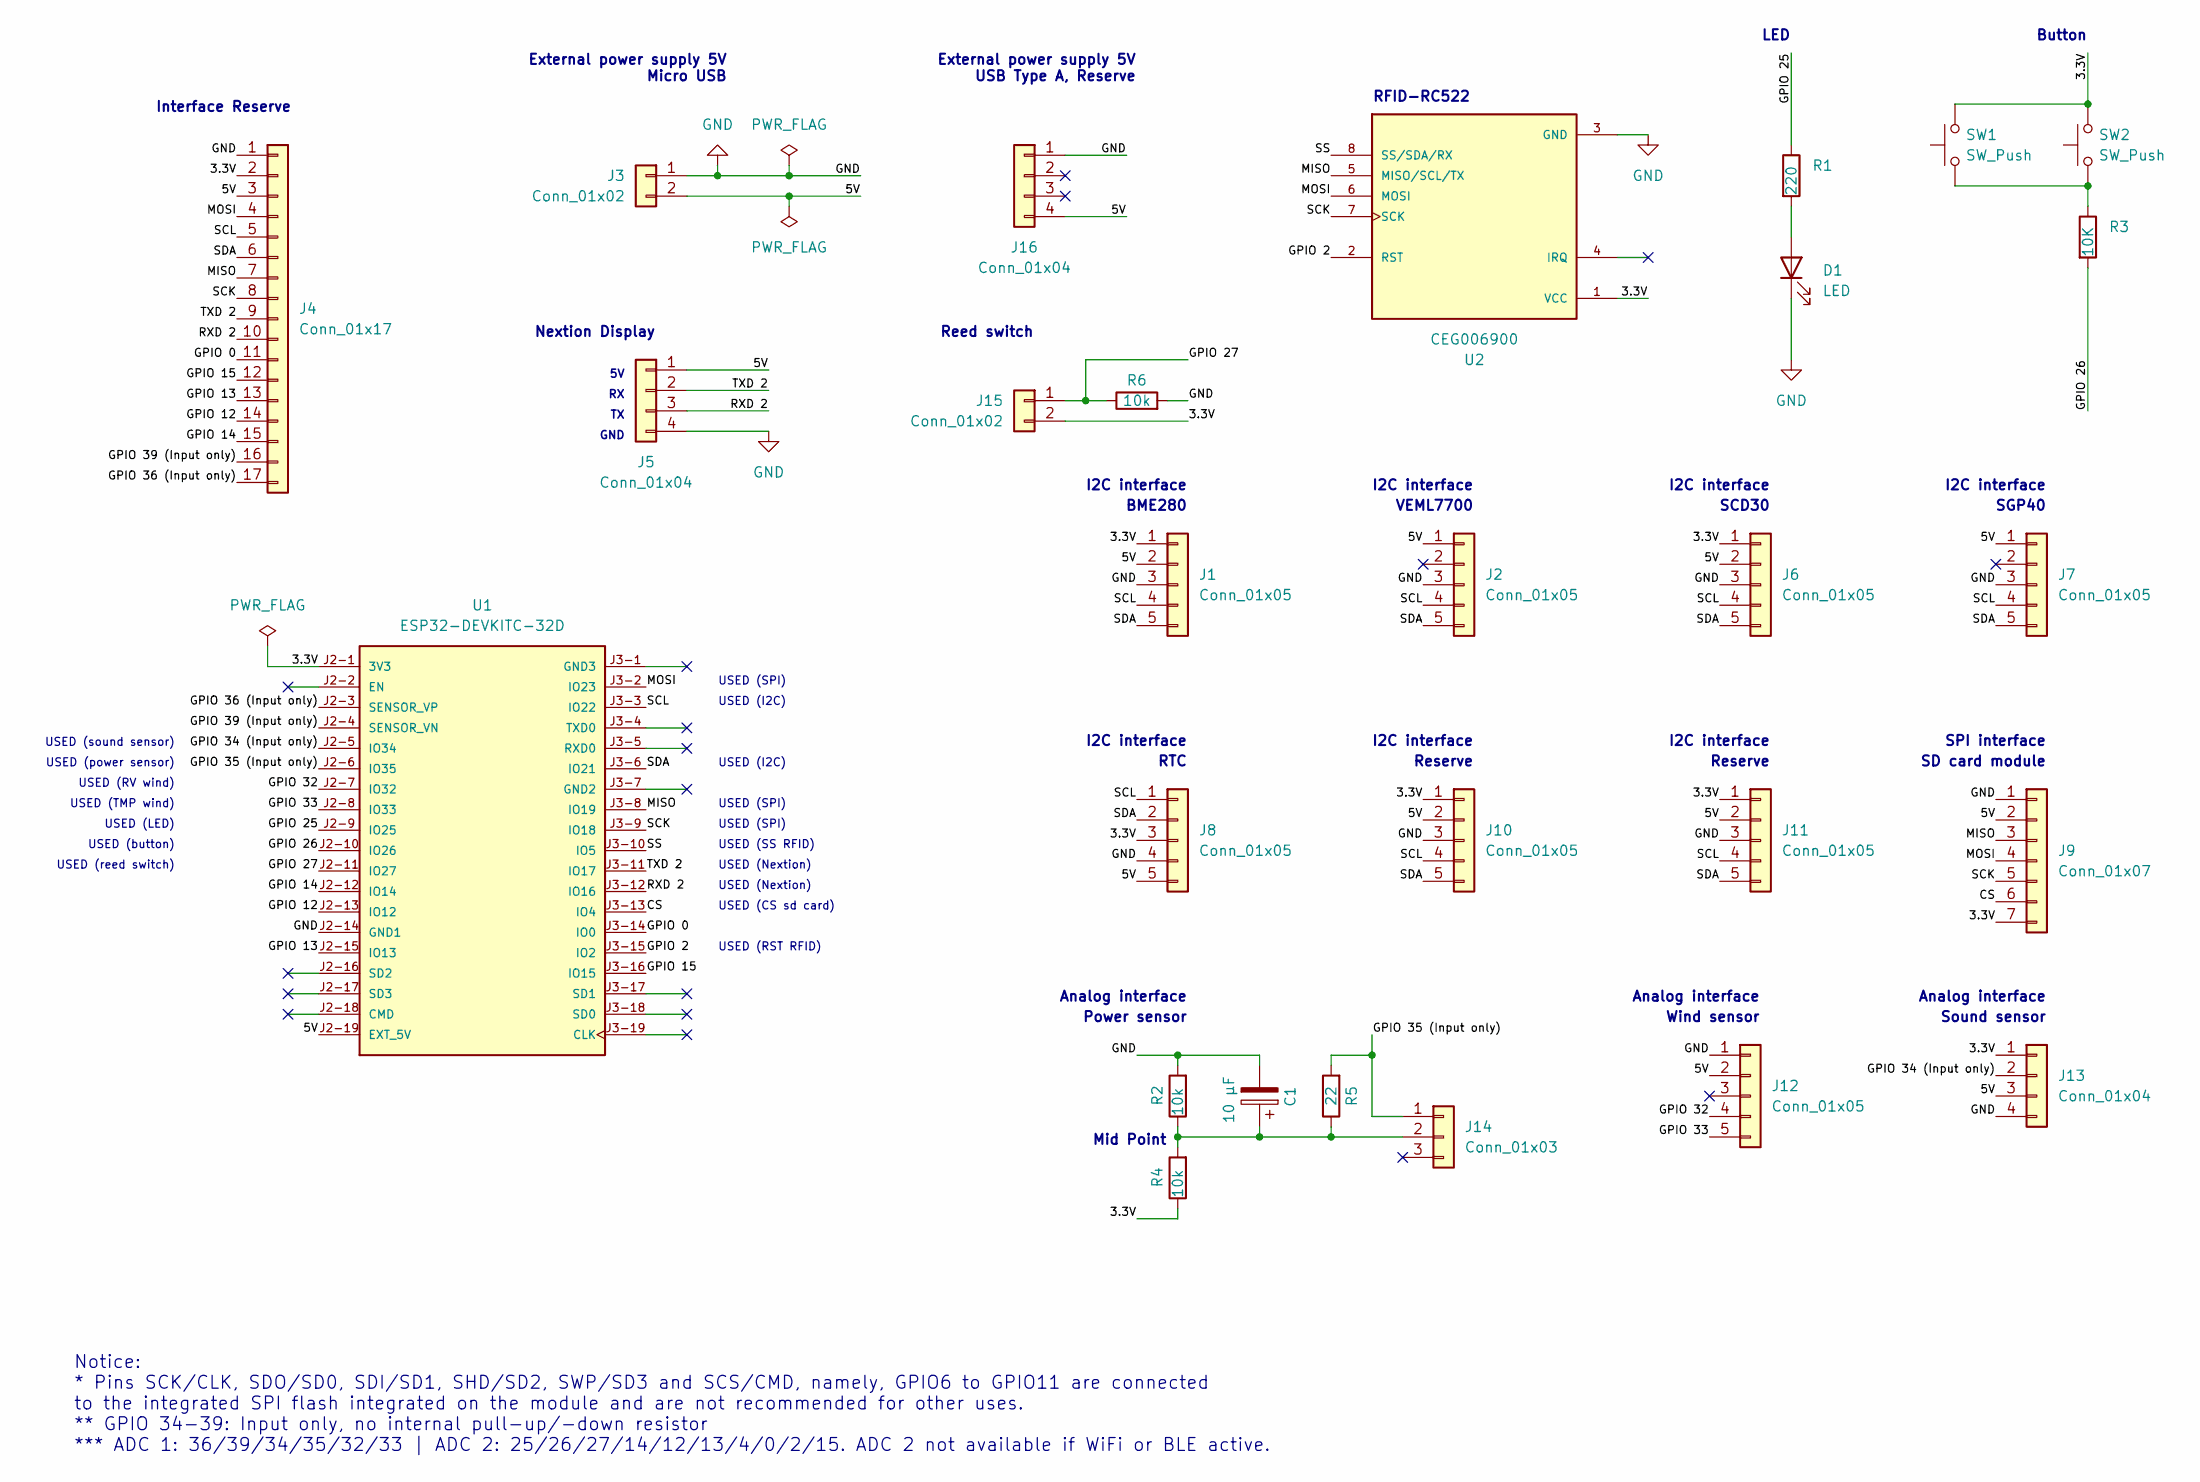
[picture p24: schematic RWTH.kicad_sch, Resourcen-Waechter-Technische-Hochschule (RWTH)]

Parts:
C1: 10 µF; CP_Radial_D5.0mm_P2.50mm
D1: LED; LED_D3.0mm
J1, J2, J6, J7, J8, J10, J11, J12: Conn_01x05; PinSocket_1x05_P2.54mm_Vertical
J3, J15: Conn_01x02; PinSocket_1x02_P2.54mm_Vertical
J4: Conn_01x17; PinSocket_1x17_P2.54mm_Vertical
J5, J13, J16: Conn_01x04; PinSocket_1x04_P2.54mm_Vertical
J9: Conn_01x07; PinSocket_1x07_P2.54mm_Vertical
J14: Conn_01x03; PinSocket_1x03_P2.54mm_Vertical
R1: 220; R_Axial_DIN0207_L6.3mm_D2.5mm_P10.16mm_Horizontal
R2, R4, R6: 10k; R_Axial_DIN0207_L6.3mm_D2.5mm_P10.16mm_Horizontal
R3: 10K; R_Axial_DIN0207_L6.3mm_D2.5mm_P10.16mm_Horizontal
R5: 22; R_Axial_DIN0207_L6.3mm_D2.5mm_P10.16mm_Horizontal
SW1: SW_Push; SW_Cherry_MX_1.00u_PCB
SW2: SW_Push; SW_PUSH_6mm_H9.5mm
U1: ESP32-DEVKITC-32D; MODULE_ESP32-DEVKITC-32D; PARTREV V4
U2: CEG006900; MODULE_CEG006900; PARTREV 12 June 2019

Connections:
/3.3V: J1.1, J4.2, J6.1, J8.3, J9.7, J10.1, J11.1, J13.1, J15.2, R4.1, SW1.2, SW2.2, U1.J2-1 (3V3), U2.1 (VCC)
/5V: J1.2, J2.1, J3.2, J4.3, J5.1, J6.2, J7.1, J8.5, J9.2, J10.2, J11.2, J12.2, J13.3, J16.4, U1.J2-19 (EXT_5V)
/CS: J9.6, U1.J3-13 (IO4)
/GPIO 0: J4.11, U1.J3-14 (IO0)
/GPIO 2: U1.J3-15 (IO2), U2.2 (RST)
/GPIO 12: J4.14, U1.J2-13 (IO12)
/GPIO 13: J4.13, U1.J2-15 (IO13)
/GPIO 14: J4.15, U1.J2-12 (IO14)
/GPIO 15: J4.12, U1.J3-16 (IO15)
/GPIO 25: R1.1, U1.J2-9 (IO25)
/GPIO 26: R3.2, U1.J2-10 (IO26)
/GPIO 27: J15.1, R6.1, U1.J2-11 (IO27)
/GPIO 32: J12.4, U1.J2-7 (IO32)
/GPIO 33: J12.5, U1.J2-8 (IO33)
/GPIO 34 (Input only): J13.2, U1.J2-5 (IO34)
/GPIO 35 (Input only): J14.1, R5.2, U1.J2-6 (IO35)
/GPIO 36 (Input only): J4.17, U1.J2-3 (SENSOR_VP)
/GPIO 39 (Input only): J4.16, U1.J2-4 (SENSOR_VN)
/MISO: J4.7, J9.3, U1.J3-8 (IO19), U2.5 (MISO/SCL/TX)
/MOSI: J4.4, J9.4, U1.J3-2 (IO23), U2.6 (MOSI)
/RXD 2: J4.10, J5.3, U1.J3-12 (IO16)
/SCK: J4.8, J9.5, U1.J3-9 (IO18), U2.7 (SCK)
/SCL: J1.4, J2.4, J4.5, J6.4, J7.4, J8.1, J10.4, J11.4, U1.J3-3 (IO22)
/SDA: J1.5, J2.5, J4.6, J6.5, J7.5, J8.2, J10.5, J11.5, U1.J3-6 (IO21)
/SS: U1.J3-10 (IO5), U2.8 (SS/SDA/RX)
/TXD 2: J4.9, J5.2, U1.J3-11 (IO17)
GND: C1.2, D1.1 (K), J1.3, J2.3, J3.1, J4.1, J5.4, J6.3, J7.3, J8.4, J9.1, J10.3, J11.3, J12.1, J13.4, J16.1, R2.2, R6.2, U1.J2-14 (GND1), U2.3 (GND)
unnamed: D1.2 (A), R1.2
unnamed: C1.1, J14.2, R2.1, R4.2, R5.1
unnamed: R3.1, SW1.1, SW2.1

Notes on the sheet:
Reed switch
I2C interface
USED (Nextion)
Analog interface
SD card module
SCD30
USED (sound sensor)
Power sensor
USED (LED)
LED
SGP40
SPI interface
Mid Point
Nextion Display
USED (I2C)
Wind sensor
USED (CS sd card)
USED (power sensor)
Reserve
USED (RV wind)
Sound sensor
USED (reed switch)
Notice: * Pins SCK/CLK, SDO/SD0, SDI/SD1, SHD/SD2, SWP/SD3 and SCS/CMD, namely, GPIO6 to GPIO11 are connected to the integrated SPI flash integrated on the module and are not recommended for other uses. ** GPIO 34-39: Input only, no internal pull-up/-down resistor *** ADC 1: 36/39/34/35/32/33 | ADC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
RFID-RC522
External power supply 5V Micro USB
RTC
VEML7700
External power supply 5V USB Type A, Reserve
USED (button)
BME280
Interface Reserve
USED (SPI)
Button
USED (SS RFID)
USED (TMP wind)
USED (RST RFID)
GND

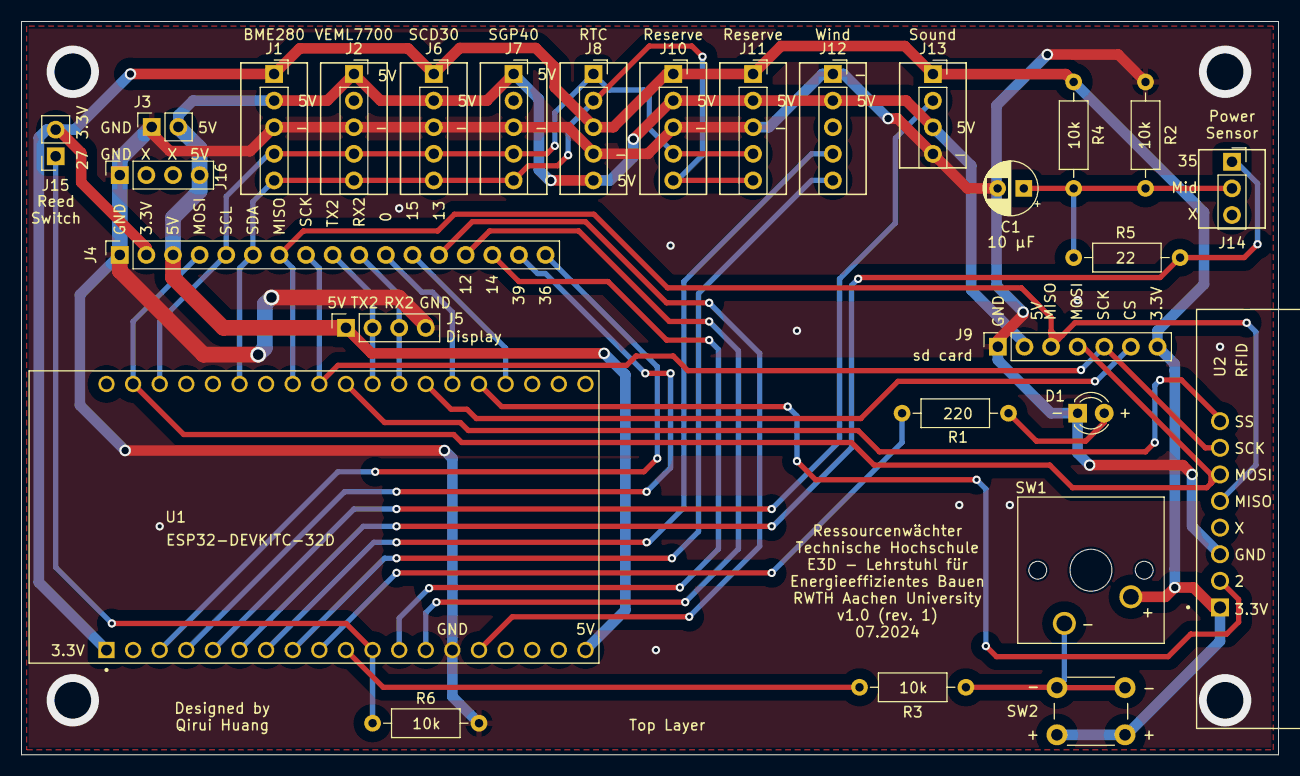
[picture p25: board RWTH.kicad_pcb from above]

Board: 2 copper layers, 120.0 x 70.0 mm, 28 parts (0 on the bottom side), 30 nets.

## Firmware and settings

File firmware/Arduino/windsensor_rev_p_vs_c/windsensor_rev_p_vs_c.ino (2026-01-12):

/*
  Comparison of Modern Device Wind Sensor Rev. P and C
  Author: Qirui Huang
  
  Email: qirui.huang@e3d.rwth-aachen.de
  MCU: ESP-32 Dev Kit C V4
  
  License: GNU GPL-3.0
*/
// ==== Sensor pins ====
#define analogPinRVRevC    34   // RV pin for Rev. C
#define analogPinTMPRevC   35   // TMP pin for Rev. C
#define analogPinRVRevP    32   // RV/OUT pin for Rev. C
#define analogPinTMPRevP   33   // TMP pin for Rev. P

// ==== ADC setting for all analog sensors ====
#define VREF  3.3  // voltage on AREF pin, default:operating voltage
#define ADCrange  4095  // range for ADC, Arduino Nano has 10bit ADC (1024: 0-1023), ESP32 12bit (4096: 0-4095)

// ==== Calibration ====
// to calibrate the sensor, put a glass over it, but the sensor should not be
// touching the glass/desktop surface however.
// adjust the zeroWindAdjustment until your sensor reads about zero with the glass over it. 
const float zeroWindAdjustment_RevC_method1 = -2.55;
const float zeroWindAdjustment_RevC_method2 = -2.55;
const float zeroWindAdjustment_RevC_method3 = 1.0;
// no adjustment for method 4
const float zeroWind_V_RevP_method5 = 0.98;

// ==== Constants (method 3) ====
const float K1 = 15.36921;
const float K2 = 0.01788;
const float K3 = -29.04560;
const float K4 = 1.01536;
const float T_rev_c = 21.9;

// ==== Libraries ====
#include <Wire.h>
#include <Adafruit_Sensor.h>
#include <Adafruit_BME280.h>

Adafruit_BME280 bme;
 
// ==== Variables ====
// raw value Rev C
float TMP_Therm_ADunits_RevC;
float RV_Wind_ADunits_RevC;
float RV_Wind_Volts_RevC;
// raw value Rev P
float TMP_Therm_ADunits_RevP;
float RV_Wind_ADunits_RevP;
float RV_Wind_Volts_RevP;
// method 1
float TempCtimes100;
float zeroWind_ADunits;
float zeroWind_volts_method1;
float WindSpeed_MPH_RevC_1;
float WindSpeed_RevC_1;
// method 2
float A;
float zeroWind_volts_method2;
float WindSpeed_MPH_RevC_2;
float WindSpeed_RevC_2;
// method 3
float RV_Wind_ADunits_RevC_1000;
float TempBME;
float WindSpeed_RevC_3;
// method 4
float WindSpeed_MPH_RevP_4;
float WindSpeed_RevP_4;
// method 5
float tempC_RevP;
float WindSpeed_MPH_RevP_5;
float WindSpeed_RevP_5;
// time
unsigned long lastMillis;


void setup() {
  Serial.begin(9600);
  Serial.println("start");
  //initialize BME280
  if (!bme.begin(0x76)) {
    Serial.println("Could not find a valid BME280 sensor, check wiring!");
    while (1);
  }
}

void loop() {
  if (millis() - lastMillis > 2000){      // read every 2000 ms - printing slows this down further
    
    // reading air temperature
    TempBME = bme.readTemperature();      // temperature value from sensor BME280
    Serial.print("TempBME degC;");
    Serial.print(TempBME);
    Serial.print(";");
    
    // reading analog values from wind sensors
    // averaging sampling for denoising
    // Rev. C
    RV_Wind_ADunits_RevC = analogRead(analogPinRVRevC);     // 1st reading
    TMP_Therm_ADunits_RevC = analogRead(analogPinTMPRevC);  // 1st reading
    for (int i=0; i<9; i++){                                // 9 additional readings
      RV_Wind_ADunits_RevC += analogRead(analogPinRVRevC);
      TMP_Therm_ADunits_RevC += analogRead(analogPinTMPRevC);
    } 
    RV_Wind_ADunits_RevC /=10;                              // average
    TMP_Therm_ADunits_RevC /=10;                            // average
    Serial.print("RV_Wind_ADunits_RevC;");
    Serial.print(RV_Wind_ADunits_RevC);
    Serial.print(";");
    Serial.print("TMP_Therm_ADunits_RevC;");
    Serial.print(TMP_Therm_ADunits_RevC);
    Serial.print(";");
    
    RV_Wind_Volts_RevC = (RV_Wind_ADunits_RevC * VREF / ADCrange);
    Serial.print("RV_Wind_Volts_RevC;");
    Serial.print(RV_Wind_Volts_RevC);
    Serial.print(";");
    

    // Rev. P
    RV_Wind_ADunits_RevP = analogRead(analogPinRVRevP);     // 1st reading
    TMP_Therm_ADunits_RevP = analogRead(analogPinTMPRevP);  // 1st reading
    for (int i=0; i<9; i++){                                // 9 additional readings
      RV_Wind_ADunits_RevP += analogRead(analogPinRVRevP);
      TMP_Therm_ADunits_RevP += analogRead(analogPinTMPRevP);
    }
    RV_Wind_ADunits_RevP /=10;                              // average
    TMP_Therm_ADunits_RevP /=10;                            // average
    Serial.print("RV_Wind_ADunits_RevP;");
    Serial.print(RV_Wind_ADunits_RevP);
    Serial.print(";");
    Serial.print("TMP_Therm_ADunits_RevP;");
    Serial.print(TMP_Therm_ADunits_RevP);
    Serial.print(";");
    
    RV_Wind_Volts_RevP = (RV_Wind_ADunits_RevP * VREF / ADCrange);
    Serial.print("RV_Wind_Volts_RevP;");
    Serial.print(RV_Wind_Volts_RevP);
    Serial.print(";");
    
    
    /* -------------- Method 1 --------------
     * Regression function provided by the manufacturer
     * https://github.com/moderndevice/Wind_Sensor
     * -------------------------------------- */
    TempCtimes100 = (0.005 *(TMP_Therm_ADunits_RevC * TMP_Therm_ADunits_RevC)) - (16.862 * TMP_Therm_ADunits_RevC) + 9075.4;  // Temperature in C times 100
    
    zeroWind_ADunits = -0.0006 *(TMP_Therm_ADunits_RevC * TMP_Therm_ADunits_RevC) + 1.0727 * TMP_Therm_ADunits_RevC + 47.172;  // 13.0C  553  482.39
    
    zeroWind_volts_method1 = (zeroWind_ADunits * VREF/ADCrange) - zeroWindAdjustment_RevC_method1;  // VREF / ADCrange instead of 0.0048828125, in our case it's 3.3 / 4095 (12-bit ADC, 3.3V ESP32)
    Serial.print("zeroWind_volts Rev C Method 1;");
    Serial.print(zeroWind_volts_method1);
    Serial.print(";");
    
    WindSpeed_MPH_RevC_1 =  pow(((RV_Wind_Volts_RevC - zeroWind_volts_method1) /.2300) , 2.7265);  
    WindSpeed_RevC_1 = WindSpeed_MPH_RevC_1 * 0.44704; // mph -> m/s
    Serial.print("WindSpeed m/s Rev C Method 1;");
    Serial.print(WindSpeed_RevC_1);
    Serial.print(";");
    
    /* -------------- Method 2 --------------
     * slightly modified formula from doi:10.3390/s150613012
     * only changing the power (A) of the first formula (2.7265, see above)
     * -------------------------------------- */
    A = -4.089 * pow(RV_Wind_Volts_RevC, 2) + 22.697 * RV_Wind_Volts_RevC - 29.371;
    zeroWind_volts_method2 = (zeroWind_ADunits * VREF / ADCrange) - zeroWindAdjustment_RevC_method2;
    Serial.print("zeroWind_volts Rev C Method 2;");
    Serial.print(zeroWind_volts_method2);
    Serial.print(";");

    float baseValue = (RV_Wind_Volts_RevC - zeroWind_volts_method2) / 0.2300;
    WindSpeed_MPH_RevC_2 =  pow(baseValue, A);
    WindSpeed_RevC_2 = WindSpeed_MPH_RevC_2 * 0.44704;
    Serial.print("WindSpeed m/s Rev C Method 2;");
    Serial.print(WindSpeed_RevC_2);
    Serial.print(";");
      
    /* -------------- Method 3 --------------
     * New regression function from doi:10.1016/j.indenv.2024.100048
     * Temperature is introduced as a correction factor, 
     * so additional temperature data is required, for example from the BME280.
     * -------------------------------------- */
    RV_Wind_ADunits_RevC_1000 = RV_Wind_ADunits_RevC / 1000; //correcting the error by dividing by 1000
    WindSpeed_RevC_3 = (2.285 * (pow(RV_Wind_ADunits_RevC_1000, 3))- 12.417 * (pow(RV_Wind_ADunits_RevC_1000, 2)) + 22.831 * RV_Wind_ADunits_RevC_1000 - 14.19)/(K4 - (T_rev_c-TempBME) * K1 * pow(RV_Wind_ADunits_RevC_1000, K3) - (T_rev_c - TempBME) * K2) - zeroWindAdjustment_RevC_method3;  //new formula
    Serial.print("WindSpeed m/s Rev C Method 3;");
    Serial.print(WindSpeed_RevC_3);
    Serial.print(";");

    /* -------------- Method 4 --------------
     * Important: For Wind Sensor Rev. P (with 12V power supply, e.g. with step-up voltage converter)!
     * From Wind Sensor Rev P Arduino sketch provided by the manufacturer
     * https://moderndevice.com/products/wind-sensor-rev-p
     * Do not use this if using ESP32 since it's 12bit ADC
     * -------------------------------------- */
    // wind formula derived from a wind tunnel data, annemometer and some fancy Excel regressions
    // this scalin doesn't have any temperature correction in it yet
    WindSpeed_MPH_RevP_4 =  pow(((RV_Wind_ADunits_RevP - 264) / 85.6814), 3.36814); // no temperature correction
    WindSpeed_RevP_4 = WindSpeed_MPH_RevP_4 * 0.44704;  // mph -> m/s
    Serial.print("WindSpeed m/s Rev C Method 4;");
    Serial.print(WindSpeed_RevP_4);
    Serial.print(";");
    
    /* -------------- Method 5 --------------
     * Important: For Wind Sensor Rev. P (with 12V power supply, e.g. with step-up voltage converter)!
     * Regression function provided by the manufacturer
     * https://moderndevice.com/blogs/documentation/calibrating-the-rev-p-wind-sensor-from-a-new-regression
     * -------------------------------------- */
    tempC_RevP = ((TMP_Therm_ADunits_RevP * VREF / ADCrange) - 0.400) / .0195; // VREF & ADCrange instead of 5.0 & 1023 due to 12-bit ADC and 3.3V (ESP32)
    Serial.print("tempC_RevP Method 5;");
    Serial.print(tempC_RevP);
    Serial.print(";");
    
    WindSpeed_MPH_RevP_5 = pow(((((RV_Wind_ADunits_RevP * VREF / ADCrange) - zeroWind_V_RevP_method5) / (3.038517 * pow(tempC_RevP, 0.115157 ))) / 0.087288 ), 3.009364);
    WindSpeed_RevP_5 = WindSpeed_MPH_RevP_5 * 0.44704;  // mph -> m/s
    Serial.print("WindSpeed m/s Rev P Method 5;"); 
    Serial.print(WindSpeed_RevP_5);
    Serial.println(";");
    
    
    lastMillis = millis();
  }
} 

 
  

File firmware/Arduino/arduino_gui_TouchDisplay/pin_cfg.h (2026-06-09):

#ifndef PIN_CFG_H
#define PIN_CFG_H

// Pin configuration

// ==== T/H/P: BME 280 ====
#define I2C_BME280                    0x76   // I2C

// ==== VOC: SGP40 ====
#define I2C_SGP40                     0x59   // I2C, it has only one I2C address, default address hardcoded in Adafruit library (not used in setup)

// ==== light: VEML7700 ====
#define I2C_VEML7700                  0x10   // I2C, it has only one I2C address, default address hardcoded in Adafruit library (not used in setup)

// ==== CO2: SCD30 ====
#define I2C_SCD30                     0x61   // I2C, it has only one I2C address, default address hardcoded in Adafruit library (not used in setup)

// ==== CO2: SCD40/41 ====
#define I2C_SCD40                     0x62   // I2C, SCD4x (40 or 41) uses fixed address 0x62

// ==== sound: SEN 0232 ====
#define analogPinSoundSensor          34      // analog pin, this pin read the analog voltage from the sound level meter

// ==== wind speed: Modern Device WindSensor Rev. C ====
#define analogPinForRV                32      // analog pin
#define analogPinForTMP               33      // analog pin

// ==== window sensor (reed switch) ====
#define digitalPinReedSwitch          27      // digital pin for window sensor input

// ==== power/current sensor ====
#define analogPinPowerSensor          35      // analog pin

// ==== OneWire bus for radiation temperature sensor DS18B20 ====
#define ONE_WIRE_BUS                  15      // digital pin for OneWire bus

// ==== RFID / SD card ====
#define RST_PIN                       0       // RST
#define SS_PIN                        5       // SS

// ==== SD card ====
#define CS_PIN                        4       // CS

// ==== sleep mode ====
#define digitalPinLED                 25      // Pin for LED
#define digitalPinSleepModeButton     26      // Pin for sleep mode button

#endif

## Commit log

2026-01-05 Upload 3d printing files
    [All_EnclosureBaseAndTop.3mf, Part1of2_EnclosureTop.3mf, Part2of2_EnclosureBase.3mf]
2026-01-05 Upload enclosure models
    [enclosure_base.stp, enclosure_display_case.stl, enclosure_display_case.stp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]
2026-01-05 Upload PCB production files
    [RWTH-B_Cu.gbr, RWTH-B_Mask.gbr, RWTH-B_Paste.gbr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]
2026-01-05 Upload PCB schematics
2026-04-23 upload KiCAD files
    [RWTH.kicad_pcb, RWTH.kicad_sch]
2026-06-09 Firmware v1.3.0: support Sensirion SCD4x CO2 sensors (SCD40/41)
